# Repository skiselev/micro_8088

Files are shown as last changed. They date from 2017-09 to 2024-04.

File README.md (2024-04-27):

# Micro 8088
IBM XT Compatible Processor Board based on Faraday FE2010/FE2010A chipset

## Introduction
Micro 8088 is an easy to build IBM PC/XT compatible processor board. It uses a fairly common Faraday FE2010/FE2010A chipset, that implements most of IBM PC/XT LSIs (Intel 8xxx ICs) and glue logic. Micro 8088 uses SRAM ICs to implement the system RAM, and a Flash ROM IC to store the BIOS, further reducing the number of components, and simplifying the build process.

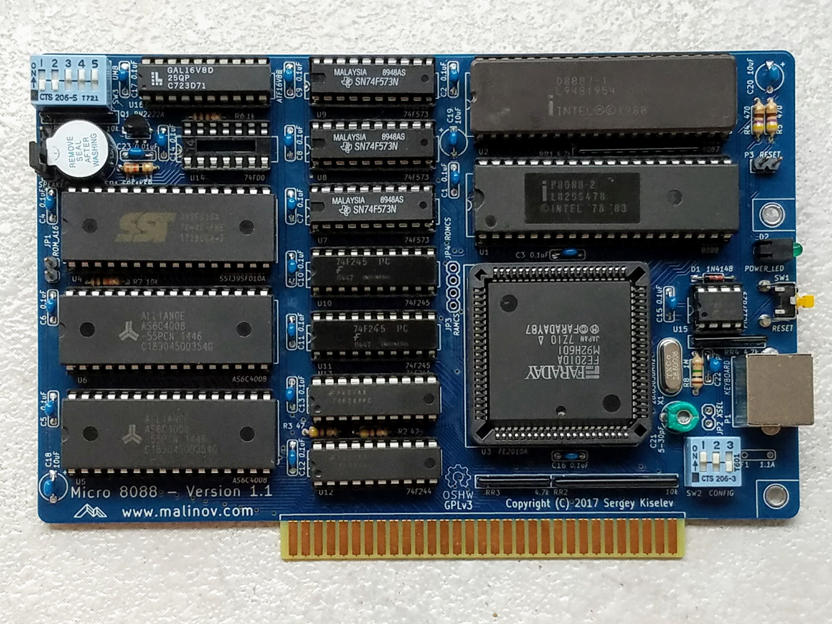
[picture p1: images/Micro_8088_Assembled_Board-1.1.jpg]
Micro 8088 V1.1 Assembled Board


## Specifications
* Processor: Intel 8088 or compatible, NEC V20
  * Supports IBM PC/XT standard 4.77 MHz CPU frequency and, when using FE2010A chipset, 7.16 MHz and 9.54 MHz CPU frequencies
* Coprocessor: Intel 8087
* [Faraday FE2010/FE2010A](Documentation/Faraday-XT_Controller-FE2010A.md) chipset, implementing the following components:
  * One 8237 direct memory access controller (DMAC)
  * One 8259 programmable interrupt controller (PIC)
  * One 8254 programmable interval timer (PIT)
  * One 8255 programmable peripheral interface (PPI)
  * Clock generation, and glue logic
* RAM: 512 KiB or 640 KiB base memory; Up to 192 KiB UMBs. Implemented using SRAM
* ROM: 64 KiB. Implemented using 128 KiB Flash ROM
* 8-bit ISA interface
* PS/2 compatible keyboard connector; built in AT2XT converter

## Hardware Documentation

### Schematic and PCB Layout

[Schematic - Version 1.1](KiCad/8088-FE2010A-SBC-Schematic-1.1.pdf)

[PCB Layout - Version 1.1](KiCad/8088-FE2010A-SBC-Board-1.1.pdf)

[PCB Layout - Version 1.2](KiCad/8088-FE2010A-SBC-Board-1.2.pdf)

[PCB Layout - Version 1.3](KiCad/8088-FE2010A-SBC-Board-1.3.pdf)

### Building Insturctions

Please refer to [Building Instructions](Building_Instructions.md) page for detailed instructions.

### Faraday FE2010/FE2010A Information

Please refer to [Faraday FE2010A documentation](Documentation/Faraday-XT_Controller-FE2010A.md) and [Faraday FE2010 datasheet](Documentation/Faraday-XT_Controller-FE2010.pdf) for detailed information about Faraday FE2010/FE2010A chipsets.

*Note: CPU clock frequency switching (turbo mode) is only implemented in Faraday FE2010A chipset (not in FE2010).*

### Jumpers, Connectors, and Switches

#### P1 - PS/2 Keyboard
Pin | Description
--- | -----------
1   | Keyboard data
2   |	Unused
3   |	GND
4   |	+5V
5   |	Keyboard clock
6   |	Unused

#### P2 - Speaker
Pin | Description
--- | -----------
1   | Speaker output
2   | Internal Speaker input*
3   | Unused
4   |	+5V

*Note: To enable internal speaker connect a jumper across pins 1-2*

#### P3 - Reset Switch
Pin | Description
--- | -----------
1   | Reset input
2   | Ground

#### JP1 - Select Flash ROM area mapped to 0xF0000-0xFFFFF
Position | Description
-------- | -----------
*open (default)* | Map lower 64 KiB of the Flash ROM to 0xF0000-0xFFFFF
closed   | Map upper 64 KiB of the Flash ROM to 0xF0000-0xFFFFF

#### JP2 - Select X1 Crystal Frequency
Position | Description
-------- | -----------
open     | Use 14.31818 MHz crystal
*closed (default)* | Use 28.63636 MHz crystal

*Note: 14.31818 MHz crystal supports 4.77 MHz and 7.16 MHz CPU clock frequencies; 28.63636 MHz crystal additionally supports 9.55 MHz CPU clock frequency*

#### JP3 - RAM Chip Select Source
Position | Description
-------- | -----------
*open (default)* | Use SPLD (U16)
closed   | Use FE2010A (U3)

*Note: FE2010A only generates RAM chip select for the base RAM (lower 640 KiB). It does not generate RAM chip select for UMBs, and therefore SPLD (U16) is required to implement UMBs*

#### JP4 - Flash ROM Chip Select Source
Position | Description
-------- | -----------
*open (default)* | Use SPLD (U16)
closed   | Use FE2010A (U3)

*Note: FE2010A does not generate chip select for memory write cycles, therefore it does not support in-system BIOS upgrades*

#### SW1 - Reset Switch
Press SW1 to reset the system

#### SW2 - System Configuration
Position	| Description
-------- | -----------
SW2.1 = OFF, SW2.2 = OFF | MDA or Hercules
SW2.1 = ON, SW2.2 = OFF  | CGA, 80x25
SW2.1 = OFF, SW2.2 = ON  | CGA, 40x25
SW2.1 = ON, SW2.2 = ON   | None, EGA, or VGA
SW2.3 = OFF | Disable keyboard 0xE0 scan code pass through
SW2.3 = ON | Enable keyboard 0xE0 scan code pass through

#### SW3 - UMB Configuration
Position	| Description
-------- | -----------
SW3.1 = ON | Map 0xC0000-0xC7FFF to RAM 
SW3.2 = ON | Map 0xC8000-0xCFFFF to RAM 
SW3.3 = ON | Map 0xD0000-0xD7FFF to RAM 
SW3.4 = ON | Map 0xD8000-0xDFFFF to RAM 
SW3.5 = ON | Map 0xE0000-0xEFFFF to RAM

*Note: SPLD (U16) is required to implement UMBs. This switch is not used in systems without SPLD*

### Bill of Materials - Versions 1.1, 1.2, and 1.3

[Micro 8088 project on Mouser.com](https://www.mouser.com/ProjectManager/ProjectDetail.aspx?AccessID=57e2f0df1d) - View and order all components except of the Faraday FE2010A chipset, and the PCB.
[Micro 8088 project on OSH Park](https://oshpark.com/shared_projects/xbWzfre6) - View and order the PCB.

Component type    	| Reference | Description                       | Quantity | Possible sources and notes 
------------------ | --------- | --------------------------------- | -------- | --------------------------
PCB                |           | Micro 8080 PCB - Version 1.1, 1.2, or 1.3 | 1        | Refer to the [RetroBrew Computers Board Inventory](https://retrobrewcomputers.org/doku.php?id=boardinventory#xi_8088_project_sergey_kiselev) page for ordering information, or order from a PCB manufacturer of your choice using provided Gerber or KiCad files
Integrated Circuit | U1        | Intel 8088, 80C88, or NEC V20 CPU | 1        | eBay, Mouser (expensive) - [968-CP80C88-2Z](https://www.mouser.com/ProductDetail/968-CP80C88-2Z)
Integrated Circuit | U2        | Intel 8087 FPU                    | 1        | Optional, eBay
Integrated Circuit | U3        | Faraday FE2010A                   | 1        | eBay, can be replaced with [Proton PT8010AF](https://github.com/skiselev/micro_8088/blob/master/Documentation/Proton-XT_Controller-PT8010AF.md)
Integrated Circuit | U4        | SST39SF010A Flash ROM, DIP-32 package | 1    | Mouser [804-39SF010A7CPHE](https://www.mouser.com/ProductDetail/804-39SF010A7CPHE)
Integrated Circuit | U5, U6    | AS6C4008 SRAM, DIP-32 package     | 2        | Mouser [913-AS6C4008-55PCN](https://www.mouser.com/ProductDetail/913-AS6C4008-55PCN)
Integrated Circuit | U7 - U9   | 74F573 Octal D-Type Latch         | 3        | Mouser [595-SN74F573N](https://www.mouser.com/ProductDetail/595-SN74F573N)
Integrated Circuit | U10, U11  | 74F245 Octal Bus Transceiver      | 2        | Mouser [595-SN74F245N](https://www.mouser.com/ProductDetail/595-SN74F245N)
Integrated Circuit | U12, U13  | 74F244 Octal Buffer               | 2        | Mouser [595-SN74F244N](https://www.mouser.com/ProductDetail/595-SN74F244N)
Integrated Circuit | U14       | 74F00 Quad 2-Input NAND Gate      | 1        | Mouser [595-SN74F00](https://www.mouser.com/ProductDetail/595-SN74F00N). **Important note: install either U14 or U16, not both together**
Integrated Circuit | U15       | PIC12F629 Microcontroller         | 1        | Mouser [PIC12F629-I-P](https://www.mouser.com/ProductDetail/579-PIC12F629IP)
Integrated Circuit | U16       | ATF16V8B SPLD                     | 1        | Mouser [556-AF16V8B15PU](https://www.mouser.com/ProductDetail/556-AF16V8B15PU). **Important note: install either U14 or U16, not both together**
IC Socket          | U1, U2    | DIP-40, 600 mil socket            | 2        | Mouser [649-DILB40P223TLF](https://www.mouser.com/ProductDetail/649-DILB40P223TLF)
IC Socket          | U3        | PLCC-84 through hole socket       | 1        | Mouser [517-8484-11B1-RK-TP](https://www.mouser.com/ProductDetail/517-8484-11B1-RK-TP)
IC Socket          | U4-U6     | DIP-32, 600 mil socket            | 3        | Mouser [649-DILB32P223TLF](https://www.mouser.com/ProductDetail/649-DILB32P223TLF)
IC Socket          | U7-U13, U16 | DIP-20, 300 mil socket          | 8        | Mouser [649-DILB20P-223TLF](https://www.mouser.com/ProductDetail/649-DILB20P-223TLF)
IC Socket          | U14       | DIP-14, 300 mil socket            | 1        | Mouser [649-DILB14P-223TLF](https://www.mouser.com/ProductDetail/649-DILB14P-223TLF)
IC Socket          | U15       | DIP-8, 300 mil socket             | 1        | Mouser [649-DILB8P223TLF](https://www.mouser.com/ProductDetail/649-DILB8P223TLF)
Diode              | D1        | 1N4148                            | 1        | Mouser [512-1N4148](https://www.mouser.com/ProductDetail/512-1N4148)
LED                | D2        | 3 mm, green LED indicator         | 1        | Mouser [LTL-4231NHBP](https://www.mouser.com/ProductDetail/859-LTL-4231NHBP)
Transistor         | Q1        | PN2222A, 2.54mm lead spacing      | 1        | Mouser [512-PN2222ATA](https://www.mouser.com/ProductDetail/512-PN2222ATA)
Crystal            | X1        | 28.63636 MHz, 18 pF, HC-49/S      | 1        | Mouser [717-9B-28.63636MAAJB](https://www.mouser.com/ProductDetail/717-9B-28.63636MAAJB)
Speaker            | SP1       | 12 mm speaker                     | 1        | Mouser [665-AT-1224TWTR](https://www.mouser.com/ProductDetail/665-AT-1224TWTR)
Tactile Button     | SW1       | 6 mm tactile button, right angle  | 1        | Mouser [653-B3F-3152](https://www.mouser.com/ProductDetail/653-B3F-3152)
DIP Switch         | SW2       | 3 positions                       | 1        | Mouser [774-2063](https://www.mouser.com/ProductDetail/774-2063)
DIP Switch         | SW3       | 5 positions                       | 1        | Mouser [774-2065](https://www.mouser.com/ProductDetail/774-2065)
Connector          | P1        | 6 pin Mini DIN, purple            | 1        | Mouser [806-KMDGX-6S-BS](https://www.mouser.com/ProductDetail/806-KMDGX-6S-BS)
Pin Header         | P2, JP3-JP4 | 4 pin header, 2.54 mm pitch     | 2        | Mouser [649-68002-104HLF](https://www.mouser.com/ProductDetail/649-68002-104HLF)
Pin Header         | P3, JP1-JP2 | 2 pin header, 2.54 mm pitch     | 3        | Mouser [649-68002-102HLF](https://www.mouser.com/ProductDetail/649-68002-102HLF)
Capacitor          | C1 - C17  | 0.1 uF, MLCC, 5 mm lead spacing   | 17       | Mouser [810-FG28X7R1H104KNT6](https://www.mouser.com/ProductDetail/810-FG28X7R1H104KNT6)
Capacitor          | C18 - C20 | 10 uF, MLCC, 5 mm lead spacing    | 3        | Mouser [810-FG28X5R1E106MR06](https://www.mouser.com/ProductDetail/810-FG28X5R1E106MR06)
Trimmer Capacitor  | C21       | 6.5-30 pF, 5 mm lead spacing      | 1        | Mouser [659-GKG30015](https://www.mouser.com/ProductDetail/659-GKG30015). Note: Trimmer capacitor is used to fine-tune 14.31818 MHz OSC frequency, and it might be needed when using CGA graphics with composite display. If not using CGA with composite display, a 22pF or so ceramic capacitor can be used instead, such as Mouser [810-FG28C0G1H220JNT6](https://www.mouser.com/ProductDetail/810-FG28C0G1H220JNT6)
Capacitor          | C22       | 47 pF, MLCC, 5 mm lead spacing    | 1        | Mouser [810-FG28C0G1H470JNT6](https://www.mouser.com/ProductDetail/810-FG28C0G1H470JNT6)
Capacitor          | C23       | 0.01 uF, MLCC, 5 mm lead spacing  | 1        | Mouser [810-FG28X7R1H103KNT6](https://www.mouser.com/ProductDetail/810-FG28X7R1H103KNT6)
Resistor Array     | RR1       | 4.7 k, bussed, 10 pin SIP         | 1        | Mouser [652-4610X-1LF-4.7K](https://www.mouser.com/ProductDetail/652-4610X-1LF-4.7K)
Resistor Array     | RR2       | 10 k, bussed, 10 pin SIP          | 1        | Mouser [652-4610X-1LF-10K](https://www.mouser.com/ProductDetail/652-4610X-1LF-10K)
Resistor Array     | RR3, RR4  | 4.7 k, bussed, 6 pin SIP          | 2        | Mouser [652-4606X-1LF-4.7K](https://www.mouser.com/ProductDetail/652-4606X-1LF-4.7K)
Resistor Array     | RR5       | 10 k, bussed, 6 pin SIP           | 1        | Mouser [652-4606X-1LF-10K](https://www.mouser.com/ProductDetail/652-4606X-1LF-10K)
Resistor           | R1        | 33 ohm, through hole              | 1        | Mouser [603-MFR-25FBF52-33R](https://www.mouser.com/ProductDetail/603-MFR-25FBF52-33R)
Resistor           | R2, R3    | 47 ohm, through hole              | 2        | Mouser [603-MFR-25FBF52-47R](https://www.mouser.com/ProductDetail/603-MFR-25FBF52-47R)
Resistor           | R4, R5    | 470 ohm, through hole             | 2        | Mouser [603-MFR-25FBF52-470R](https://www.mouser.com/ProductDetail/603-MFR-25FBF52-470R)
Resistor           | R6        | 1 kohm, through hole              | 1        | Mouser [603-MFR-25FBF52-1K](https://www.mouser.com/ProductDetail/603-MFR-25FBF52-1K)
Resistor           | R7        | 10 kohm, through hole             | 1        | Mouser [603-MFR-25FBF52-10K](https://www.mouser.com/ProductDetail/603-MFR-25FBF52-10K)
Resistor           | R8        | 1 Mohm, through hole              | 1        | Mouser [603-MFR-25FBF52-1M](https://www.mouser.com/ProductDetail/603-MFR-25FBF52-1M)
Fuse               | F1        | 1.1A polyfuse, 5.08 mm lead pitch | 1        | Mouser [650-RUSBF110-2](https://www.mouser.com/ProductDetail/650-RUSBF110-2)
ISA Bracket        |           | Keystone Electronics 9202         | 1        | Mouser [534-9202](https://www.mouser.com/ProductDetail/534-9202)
Screw              |           | 4-40 x 1/4" Screw                 | 2        | Mouser [534-9900](https://www.mouser.com/ProductDetail/534-9900)

## Firmware Documentation

### System BIOS

Micro 8088 uses a modified version of [Xi 8088](http://www.malinov.com/Home/sergeys-projects/xi-8088) BIOS. The BIOS binary images are provided in [BIOS](BIOS) directory. The BIOS source code is available in [8088_bios GitHub repository](https://github.com/skiselev/8088_bios)

#### Turbo Mode Switching

The BIOS keyboard handler uses the following key combinations to switch the CPU clock frequency:
* **Ctrl-Alt-Keypad -** - Normal 4.77 MHz CPU clock frequency
* **Ctrl-Alt-Keypad \*** - Turbo 7.16 MHz CPU clock frequency
* **Ctrl-Alt-Keypad +** - Turbo 9.55 MHz CPU clock frequency (works only on systems with 28.63636 MHz X1 crystal)

Note that the BIOS does not, and possibly can not check if the installed CPU and the FPU are actually capable of running at higher clock frequencies. Turning on the turbo mode in a system with 5 MHz CPU can make it unstable.

### AT2XT Firmware

Micro 8088 integrates an AT2XT keyboard converter, implemented using PIC12F629 (U15). The firmware for this microcontroller is availabe from the [minuszerodegrees.net](http://minuszerodegrees.net/at2xtkb/XTATKEY_094.zip) and the [Vintage Computer Federation AT2XT page](https://forum.vcfed.org/index.php?threads/at2xt-keyboard-converter.26861/page-4#post-1242916). The HEX file with the firmware can be extracted from XTATKEY_094.zip.

### SPLD Fuse Maps

An optional ATF16V8/GAL16V8 SPLD (U16) allows using spare SRAM space for UMBs, and implements Flash ROM write access. The fuse maps for the SPLD are provided in [SPLD](SPLD) directory of this repository. The [SPLD/micro_8088_prod.jed](SPLD/micro_8088_prod.jed) fuse map should be used for production applications.

## Changes
* Version 1.3
  * Update silkscreen:
    * SW2.3 - fix the description for the *ON* position
    * Add a warning about installing either U14 or U16, but not both
    * Update board version to 1.3
* Version 1.2
  * Update silkscreen:
    * JP2 - change the default to *Closed*
    * Bracket - move rectangles to the back side, add circles around mounting holes on the front side
    * Remove the line around ISA connector
    * Use KiCad OSHW logo
    * Update copyright years to 2017-2018
    * Update board version to 1.2
* Version 1.1
  * Recommend using 74F-series, and update the schematic and the silkscreen accordingly. 74F-series ICs are faster and slightly cheaper than 74ALS-series
  * Add 74F573 latch for latching A8-A11 signals. This fixes the DMA issue
  * Use 74F244 to buffer OSC and CLK signals
  * Use AS6C4008 for the second SRAM (U6) instead of AS6C1004. This resolves the AS6C1004 TTL compatibility issue
  * Use 74F00 for generating chip select signal for the second SRAM (U6), and for inverting the speaker signal
  * Add an optional SPLD (U16) to implement UMBs
  * Use 128 KiB Flash ROM instead of 32 KiB EEPROM. It is cheaper, and has twice more storage space
  * Use buffered /MEMR and /MEMW signals for SRAM and BIOS ROM
  * PCB dimensions changed from 5" x 4.3" to 6" x 4"
* Version 1.0
  * Initial version

## Known Issues
* Version 1.2
  * SW2.3 description on the back silkscreen incorrectly references SW1.3 for the *ON* position
* Version 1.1
  * JP2 description on the back silkscreen suggests that the default JP2 position is *Open*. Since the recommended chipset is FE2010A and the recommended crystal frequency is 28.63636 MHz, the default JP2 position should be *Closed*
  * Update the silkscreen near ISA bracket mounting holes: The rectangles should be moved to the back silkscreen, and screw head sized circles should be shown on the front skilscreen
* Version 1.0
  * AS6C1008 (U6) does not have TTL compatible inputs causing instability with 640 KiB memory configruation
    * Workaround: use CMOS transceiver U11, e.g. 74AHCT245
  * DMA doesn't work properly.
    * This is due to A8-A11 address lines not being latched.
    * Workaround: add a 74F573 latch, and connect AA8-AA11 and A8-AA11 through it

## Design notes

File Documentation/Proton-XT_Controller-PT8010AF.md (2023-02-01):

# Proton PT8010AF - PC Bus, CPU, and Peripheral Controller

## Introduction

Proton PT8010AF controller was used in several late 80's XT-compatible motherboards. It appears to be a clone of [Faraday FE2010A](Faraday-XT_Controller-FE2010A.md).

Unfortunately I was not able to find Proton PT8010AF datasheet, so I [reverse-engineered a PT8010AF-based motherboard](https://github.com/skiselev/Proton_Turbo_XT).
This work showed that Proton PT8010AF has exactly the same pinout as Faraday FE2010A. I also acquired a PT8010AF, installed in a Micro 8088 system, and tested it.

## Can Faraday FE2010A be replaced with Proton PT8010AF?

Proton PT8010AF will work instead of Faraday FE2010A in a Micro 8088 system. I haven't tested other systems, but it is very likely that it will work there too.

## Differences between Proton PT8010AF and Faraday FE2010A

During my testing so far, I found two differences between Proton PT8010AF and Faraday FE2010A documented below.

### DRAM Refresh

Both chipsets implement IBM PC/XT compatible memory refresh using 8253 PIT Channel 1. DRAM refresh inserts DMA cycles, so it slows down the system. My measurements show up to 15% slowdown. In both chipsets it is possible to disable the DRAM refresh if it is not needed, for example in systems like Micro 8088, that use SRAM. 

It appears that in both chipsets, the refresh is disabled by writing **0x54** to port **0x43** (PIT control register). And it enabled by a consecutive write to port **0x41** (PIT Channel 1), typically, the value written is **0x12**, which results in a 15 usec refresh interval - same as on IBM PC/XT.

There are a few differences in behavior of the PIT registers between Faraday FE2010A and Proton PT8010AF:

* When refresh is enabled, on PT8010AF, reads from **0x41** (PIT Channel 1, should result in current counter content) return numbers from **0x00** to **0x0F** (perhaps higher numbers too, theoretically should be in **0x00** to **0x11** interval), while on FE2010A such reads seem to result in either **0x10** or **0x05**.
* When refresh is enabled, on FE2010A, writing **0x40** to port **0x54** results in disabling refresh. Consecutive reads from **0x41** will result in **0x12** value, while on PT8010AF, writing **0x40** to port **0x54** does not disable refresh

### IORDY Timing

It appears that Proton PT8010AF samples IORDY input later than Faraday FE2010A does. The difference in behavior in my case is observable when running a Micro 8088 system
with a Trident TVGA9000i card, in the 9.54 MHz Turbo mode, with zero memory wait states (port 0x63 - Chipset Configuration Register, bits 7 and 5 set to 1).
In this case with a FE2010A, I observe glitches on video output, apparently resulting from the chipset ignoring VGA controller IO_CH_RDY requests to insert wait cycles
(video controllers almost always insert wait cycles when accessing video memory), while with Proton PT8010AF there are no glitches and wait states are inserted correctly.
I suspect that there is a difference in the time when IORDY is sampled, and perhaps Proton PT8010AF samples it a bit later, giving VGA controller an opportunity to activate it
before it gets sampled.

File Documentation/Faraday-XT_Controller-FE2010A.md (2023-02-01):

# Faraday FE2010A - PC Bus, CPU, and Peripheral Controller

## Introduction

Faraday FE2010A was manufactured in late 1980's and perhaps early 1990's by Western Digital Corp., which had acquired Faraday Electronics Inc. in 1987.
Faraday FE2010A is an enhanced version of Faraday FE2010 controller, the main difference is support for higher CPU clock frequencies (aka turbo mode).
Faraday FE2010A was one of the earlier PC chipsets. It implements the Intel 8xxx ICs (excluding the microprocessor and the math coprocessor)
and the glue logic found on an IBM XT motherboard. Thus, it allows implementing an XT compatible system with a minimal number of components.

I was not able to find the original Faraday FE2010A datasheet, and this document is an attempt to combine the information gathered from
various sources and experimentation.

## Detailed Description

Most of the hardware specifications of Faraday FE2010A, including the pinout are similar to Faraday FE2010, and they are documented in
the [Faraday FE2010 datasheet](https://github.com/skiselev/micro_8088/blob/master/Documentation/Faraday-XT_Controller-FE2010.pdf).

### Hardware Differences Between Faraday FE2010A and Faraday FE2010

Faraday FE2010 only supports PC/XT standard 4.77 MHz CPU clock frequency using 14.31818 crystal oscillator.
Faraday FE2010A can provide 4.77 MHz and 7.15 MHz CPU clock frequencies using 14.31818 MHz crystal oscillator,
or 4.77 MHz, 7.15 MHz, and 9.54 MHz CPU clock frequencies using 28.63636 MHz crystal oscillator.
Faraday FE2010A uses XSEL signal - pin 16 (previously unused on FE2010) to indicate the crystal frequency as follows:

* 14.31818 MHz crystal oscillator - pin 16 pulled up, e.g. connected to +5V using a 4.7 kohm resistor
* 28.63636 MHz crystal oscillator - pin 16 pulled down, e.g. connected to the ground

It seems to be a difference in the way Faraday FE2010A implements DRAM controller: Faraday FE2010 has only a single bit in the
Configuration Register to set the DRAM size, while Faraday FE2010A implements two such bits.

## Faraday FE2010A Programming

### I/O Map

Address     | I/O Resource
------------|-------------
0x00 - 0x0F | 8237 Compatible DMA Controller
0x10 - 0x1F | Reserved
0x20 - 0x21 | 8259 Compatible Interrupt Controller
0x22 - 0x3F | Reserved
0x40 - 0x42 | 8253 Compatible Timer
0x44 - 0x5F | Reserved
0x60        | Keyboard Data Register
0x61        | Control Register (aka Port B)
0x62        | Switch Register (aka Port C)
0x63        | Configuration Register
0x64 - 0x6F | Reserved
0x70 - 0x7F | Unused
0x81 - 0x83 | DMA Page Registers
0x84 - 0x9F | Reserved
0xA0        | NMI Mask Register
0xA1 - 0xFF | Reserved

The I/O space is decoded to be compatible with the IBM PC I/O decoding scheme. This means that the upper 6 address lines are not
used in decoding the I/O address. To further clarify this, the address of the NMI Mask Register is located at XXXX XX00 1010 000 binary.
X indicates a "don't care" condition.

### Keyboard Data Register

The Keyboard Data Register is a read only register that is used to read data from the keyboard. When a character is in the Keyboard Data
Register, interrupt 1 will be sent to the Interrupt Controller. The Keyboard Data Register may be cleared by setting bit 7 of Control
Register (setting it to 1 and resetting it to 0).

### DMA Page Registers

The Page Registers are write only registers used to generate address bits 16 - 19 during a DMA transfer.

Address | Page Register
--------|--------------
81      | DMA Channel 2
82      | DMA Channel 3
83      | DMA Channel 1

Data Bit | Function
---------|---------
0        | Address Bit 16
1        | Address Bit 17
2        | Address Bit 18
3        | Address Bit 19

### NMI Mask Register

The NMI Mask Register (I/O Address 0xA0) is used to enable the NMI to the CPU. It is a write only register

Data Bit | Function
---------|---------
0 - 6    | Not Used
7        | 1 = Enable NMI

### Control Register

The Control Register (I/O Address 0x61) emulates the behavior of 8255 PPI Port B, as implemented in the standard IBM XT design.
It is a read/write register: writing it controls the corresponding functions, reading it returns the last written value.

Data Bit | Function
---------|---------
0        | Timer 2 Gate
1        | Enable Speaker
2*       | Switch Select
3*       | Not Used
4        | Disable Parity Check
5        | Disable I/O Check
6        | Enable Keyboard Clock
7        | Clear Keyboard Data Register

*Note: Bits 2 and 3 are swapped when compared to the standard IBM PC architecture*

### Switch Register

The Switch Register (I/O Address 0x62) is a read/write register.
In read mode it emulates the behavior of 8255 PPI Port C, as implemented in the standard IBM XT design.
In write mode it allows setting the values for the emulated IBM XT configuration DIP switch (that can be later read from this register).

#### Switch Register Functions - Write Mode

Data Bit | Function
---------|-----------------
0        | Not Used (SW1 value)
1        | 8087 Installed (SW2 value)
2 - 3    | On Board System Memory Size (SW3 - SW4 values)
4 - 5    | Not Used (SW5 - SW6 values are set using the actual inputs from VID0 and VID1 pins)
6 - 7    | Number of Floppies (SW7 - SW8 values)

#### Switch Register Functions - Read Mode

The switch values (bits 0 - 3) depend on the Switch Select bit (bit 2) setting in the control register.

Data Bit | Function with Switch Select = 0
---------|-----------------
0 - 1    | VID0 and VID1 pins (SW5 and SW6 values)
2 - 3    | Number of Floppies, as written to bits 6 - 7 of this register (SW7 - SW8 values)
4        | Timer 2 Output
5        | Timer 2 Output
6        | I/O Channel Check
7        | RAM Parity Check

Data Bit | Function with Switch Select = 1
---------|-----------------
0        | Value written to bit 0 of this register (SW1 value)
1        | 8087 Installed, as written to bit 1 of this register (SW2 value)
2 - 3    | On Board System Memory Size as written to bits 2 - 3 of this register (SW3 - SW4 values)
4        | Timer 2 Output
5        | Timer 2 Output
6        | I/O Channel Check
7        | RAM Parity Check

### Configuration Register

The Configuration Register (I/O Address 0x63) is a write only register that is used for FE2010A configuration.
If bit 3 is written, bits 0 - 4 of this register and the switch register are locked in that they may not be written to.
This lock is removed by a system reset.

Data Bit | Function
---------|----------
0        | Disable Parity Checker
1        | Enable 8087 NMI
2        | On Board RAM size (bit 0)
3        | lock register (bits 0-4)
4        | On Board RAM size (bit 1)
5        | Fast Mode (0 RAM wait states)
6        | 7.15 MHz CPU clock
7        | 9.54 MHz CPU clock

Data bit 0 must always be one on systems without parity checking, for example in systems using SRAM.
Data bit 1 most always be zero when no 8087 is present and data bit 1 must always be a one when 8087 is present.

#### On Board RAM Size

On Board RAM size refers to the number of banks of memory supported by the FE2010A DRAM controller

Configuration Register Bit 4 | Configuration Register Bit 2 | Memory Banks | On Board RAM size
-----------------------------|------------------------------|--------------|------------------
0                            | 1                            | 1            | 256K
1                            | 0                            | 2            | 512K
0                            | 0                            | 3            | 640K

*Note: On Board RAM size settings doesn't seem to affect systems using SRAM (need check if they are not used to determine on board memory size for wait state generation)*

#### CPU Clock Frequency and Wait States

Configuration Register Bit 7 | Configuration Register Bit 6 | Configuration Register Bit 5 | CPU Speed | I/O Wait States | On Board Memory Wait States | Memory Bus Wait States
-----------------------------|------------------------------|------------------------------|-----------|-----------------|-----------------------------|----------------------- 
0                            | 0                            | X                            | 4.77 MHz  | 1               | 0                           | 0
0                            | 1                            | 0                            | 7.15 MHz  | 4               | 0                           | 2
0                            | 1                            | 1                            | 7.15 MHz  | 4               | 0                           | 0
1                            | 0                            | 0                            | 9.54 MHz  | 6               | 0                           | 4
1                            | 1                            | 0                            | 9.54 MHz  | 4               | 0                           | 2
1                            | 0                            | 1                            | 9.54 MHz  | 6               | 0                           | 0
1                            | 1                            | 1                            | 9.54 MHz  | 4               | 0                           | 0

*Note: It appears that when running at 9.54 MHz, the CPU clock duty cycle is 50% (instead of 33%). This potentially can cause issues with some 8088 CPUs.*

### Counter/Timer Control

The timer section of the FE2010A is similar in design to the Intel 8253 Programmable Interval Timer.
The timer inputs are internally connected to a 1.19 MHz clock and the outputs are appropriately connected to configure the timer
for the PC/XT architecture. Channel 0 is used by the system to provide a real time clock to interrupt 0. Channel 1 is directly connected
to the DMA channel 0 request line and provides timing for the Dynamic RAM refresh. An I/O read from port 0x41 turns refresh on and
an I/O write to port 0x43 selecting counter 1 turns refresh off. The channel 2 output is connected to the SPKR signal and provides tone
generation.

The timer may be programmed in the same manner as the 8253. It should be noted, however, that the modes of the timer defined above are
hardwired in the component and can not be changed. The timer has four registers located at I/O addresses 0x40 to 0x43.

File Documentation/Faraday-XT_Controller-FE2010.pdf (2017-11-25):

Powered by ICminer.com Electronic-Library Service CopyRight 2003

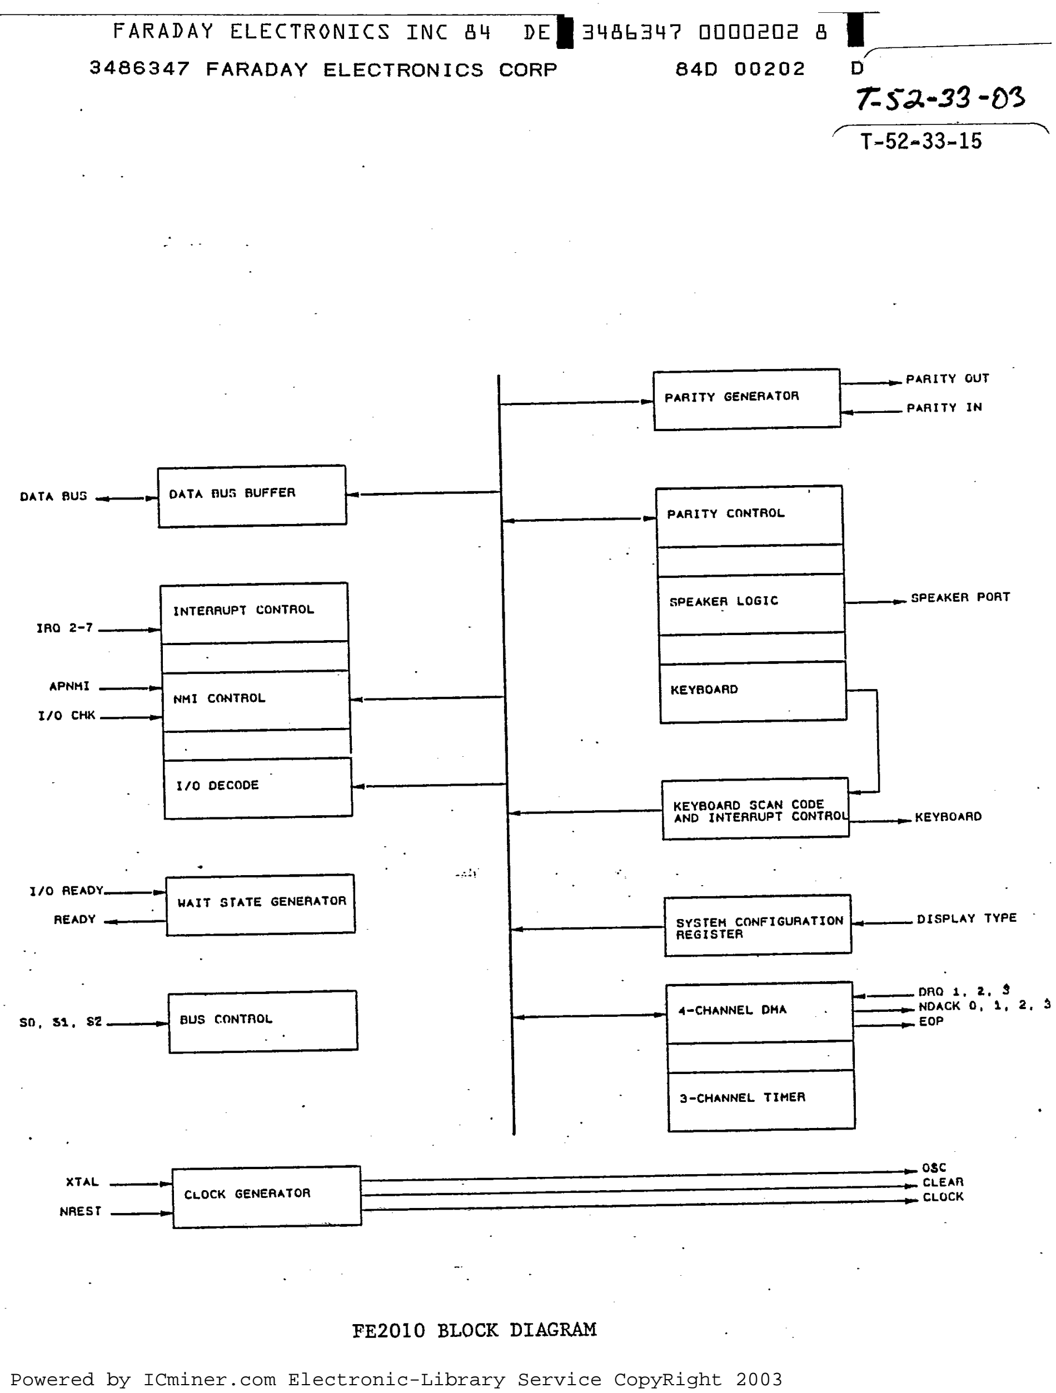
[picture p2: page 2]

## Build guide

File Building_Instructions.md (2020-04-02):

# Micro 8088 - Building Instructions

## Prerequisites

### Tools, Equipment, and Supplies

* Soldering iron with a fine tip. Temperature controlled soldering station is recommended
* Needle nose pliers for forming components' leads
* Small side cutters for cutting components' leads
* Universal programmer capable of programming SST39F010A Flash ROM ICs, PIC12F629 Microcontrollers, and ATF16V8B SPLDs. For example, MiniPro TL866CS or MiniPro TL866A
* Multimeter with frequency measurement, an oscilloscope, or a logic analyzer can be beneficial for troubleshooting
* Desk lamp, magnifying glass
* Electric drill and drill bits for drilling holes in the ISA bracket
* Small semi-round file for smoothing holes in the ISA bracket
* PLCC IC extraction tool
* Small flat and Philips screwdrivers
* Solder suitable for soldering electronics. For example: rosin core Sn63/Pb37, Sn60/Pb40, or a lead-free solder such as Sn96.5/Ag3.0/Cu0.5 (sometimes referred to as SAC305)
* Solder wick for removing excess of solder
* 99% Isopropyl Alcohol for removing the excess of flux after soldering
* Lint free wipes, used toothbrush, cotton swabs for cleaning the PCB before and after soldering

### Parts

#### Procuring Parts
The list of parts provided in the [Bill of Materials](README.md#bill-of-materials---version-11) section of the [README.md](README.md) file. It also provides the recommended sources for the parts.
Most of the parts are available from electronic components distributors such as [Mouser](https://www.mouser.com/ProjectManager/ProjectDetail.aspx?AccessID=57e2f0df1d) and [Digi-Key](https://www.digikey.com).
Many components are also available, frequently cheaper, from smaller stores, such as [Unicorn Electronics](http://www.unicornelectronics.com/), or on eBay.

The Micro 8088 PCBs are provided by the members of [RetroBrew Computers group](https://retrobrewcomputers.org/doku.php?id=boardinventory#xi_8088_project_sergey_kiselev).
Alternatively they can be ordered from a PCB manufacturing service, such as [OSH Park](https://oshpark.com/shared_projects/xbWzfre6),
using [Gerber](gerber) or [KiCad](KiCad) files provided in this GitHub repository.

Faraday FE2010A chip is available from a few sellers on eBay, and can be also obtained from some Chinese IC distributors.

The 8088 processor is no longer manufactured, but still can be obtained from several sources.
It can be replaced with CMOS version - 80C88, which is still manufactured by [Renesas/Intersil](https://www.renesas.com/us/en/products/space-harsh-environment/harsh-environment/microprocessors-peripherals/device/80C88.html).
Alternatively NEC V20 CPU can be used, this CPU is slightly faster than the original 8088, and supports 80186+ instruction set.

The 8087 math coprocessor is an optional component. Not many programs use it, and not many PCs/XTs and compatible computers in 1980's had it installed.
Still, if needed it can be obtained on eBay. Intel D8087-1 is the recommended part (-1 suffix means 10 MHz clock frequency).

#### Parts Replacement

* The recommended logic family is the Fast TTL 74F-series
  * Possible replacements are Advanced Low-Power Schottky 74ALS-series, or CMOS 74ACT-series logic
  * 74LS, 74HCT, 74AHCT series logic might work as well, but have not been tested
* The recommended CPU is 10 MHz 8088, for example AMD P8088-1, or Siemens SAB 8088-1-P
  * Possible replacements are 10 MHz or higher NEC V20 (μPD70108C-10) or NEC V20HL (μPD70108HCZ-10, μPD70108HCZ-16)
  * 8 MHz 8088-2, 80C88-2, and NEC V20 (μPD70108C-8) parts might work as well
* The recommended SPLD is Atmel ATF16V8B. It can be replaced with Lattice GAL16V8D or similar
  * Make sure that your programmer supports the SPLD type you're planning to use
  * Note that SPLD part is optional, and a 74F00 logic IC can be used instead. See the [Optional Components](#optional-components) section below.
* The recommended Flash ROM part is Microchip SST39SF010A
  * Other 128 KiB, 5V-only Flash ROM ICs can be used, for example Atmel AT29C010, Winbond W29EE011, Greenliant GLS29EE010, AMD Am29F010B
* The recommended SRAM part is Alliance Memory AS6C4008-55PCN
  * Other 512 KiB, TTL compatible SRAM ICs should work, for example Hitachi HM628512, BSI BS62LV4006PC
* It is recommended to use ceramic multilayer capacitors with 5 mm lead pitch
  * It is possible to use 2.5 mm lead pitch or axial capacitors by forming their leads accordingly
  * Electrolytic or tantalum capacitors can be used for C18-C20 10 uF. Make sure to observe the polarity in this case
* Either 28.63636 MHz or 14.81313 MHz crystal X1 can be used. The 28.63636 MHz is the recommended value. Make sure to set JP2 according to the selected crystal frequency

#### Optional Components

* Either the SPLD IC U16 or the 74F00 logic IC U14 should be installed (but not both together)
  * The SPLD provides UMB (upper memory blocks) support, and supports read/write access to the Flash ROM
  * The 74F00 supports only 640 KiB of base RAM, and allows read-only access to the Flash ROM. It is not needed to install the DIP switch SW3 if using 74F00
 * 8087 math co-processor U1 is completely optional
* The second SRAM U6 is optional, the system memory size will be limited to 512 KiB if that IC is not installed
* DIP IC sockets are optional, but it is highly recommended to install them for the following ICs:
  * Processor and math coprocessor - U1 and U2
  * PIC12F629 microcontroller - U15
  * SPLD IC - U16
  * Memory ICs - U4 - U6; or at least of the Flash ROM - U4
* The SP1 speaker is optional, and not required if using an external speaker, or no speaker at all

### Other Components Required to Build Functional Computer System

* ISA Backplane
* ISA Graphics/Display Card
* ISA Disk controller and matching disk drives
  * ISA Floppy Disk controller and Floppy drives with cables
  * XT-IDE controller and IDE disk or compact flash card
  * XT-CF-Lite controller and compact flash card
* Optionally - ISA Sound Card
* Power supply (matching the backplane)
* Case or a chassis to mount the system on, or spacers to put under the backplane
* Operating system and software to install on the system
  * MS-DOS
  * File manager and other utilities
  * Diagnostics and benchmark software
  * Games

## Building the Micro 8088 Board

### Build Sequence

1. Inspect the PCB for obvious defects, such as deep scratches or short-circuits between traces
2. Clean the PCB with an alcohol wipe
3. Solder the components, going from lower profile components to higher profile ones
  * Form the leads and solder the D1 diode. Pay attention to the diode's polarity (the black band on the diode should match the band on the silkscreen)
  * Solder the R1-R8 resistors
  * Solder the X1 crystal. You might want to place a piece of a non-conductive plastic, e.g. a nylon washer between the crystal and the PCB
  * Solder the C1-C23 capacitors. Pay attention to the capacitors polarity if using polarized capacitors
  * Solder the RR1-RR5 resistor arrays. Pay attention to the orientation - pin number 1 is usually marked with a dot on the resistor array. Square pads on the PCB are used to mark the first pin
  * Solder all the DIP sockets - U1, U2, U4 - U16. Pay close attention to the orientation of the sockets
  * Solder the PLCC socket for U3. Pay close attention to the orientation of this socket
  * Solder the DIP switches SW2 and SW3
  * Solder the LED D2. Pay attention to the LED polarity. If using a regular 3 mm LED you might want to bend its leads at the right angle, so that it points towards, and sticks through the ISA bracket
  * Solder the Q1 transistor
  * Solder the P2, P3, JP1 - JP4 headers. If using SPLD you don't need solder JP3 - JP4 headers. Also if using 28.62626 MHz crystal, a wire jumper can be installed in place of the JP2 header, or it could be left unpopulated for 14.81313 MHz crystal
  * Solder the SW1 tactile button
  * Solder the F1 polyfuse
  * Solder the P1 Mini DIN connector
  * Solder the SP1 speaker. Pay attention to the polarity
4. Carefully inspect all the solder joints. Re-solder if needed. Optionally use a multimeter to check the board for short-circuits, and for the power supply signals connectivity
5. Clean the board using cotton swaps, wipes, and the toothbrush soaked in alcohol
6. Program the Flash ROM with the [BIOS image](BIOS)
7. Program the PIC12F629 microcontroller with the [AT2XT Firmware](www.vcfed.org/forum/showthread.php?26426-AT2XT-keyboard-converter)
8. If using SPLD, program it with this [fuse map](SPLD/micro_8088_prod.jed)
9. Carefully install ICs into the sockets. Use a hard non-static surface to bend the pins of ICs in DIP packages as needed. Double check the orientation of the ICs. Make sure that all ICs pins are inserted into the sockets, and not bent. Note that FE2010A is installed upside down compared to other ICs.
10. Inspect the completed board once again
11. Install the configuration jumpers, and set the DIP switches as needed. Refer to the [Jumpers, Connectors, and Switches](README.md#jumpers-connectors-and-switches) section of the [README.md](README.md) file
12. Drill the holes in the ISA bracket to match with the PS/2 Mini DIN connector, the reset switch, and the LED. Finish the holes with a file
13. Attach the ISA bracket to the board using two 4-40 x 1/4" screws
14. Install the Micro 8088 board and other ISA cards in the ISA backplane. Connect the power supply
15. Turn on the power, test the board, install your favorite software, and enjoy!

## Troubleshooting Tips

* Inspect your board for any soldering issues
* Check the jumpers and the switches settings. Pay attention to the SW3 switch settings, and make sure that the selected UMB addresses do not conflict with BIOS extension ROMs. For example 0xC0000-0xC7FFF range is normally used by VGA BIOS, make sure that the corresponding switch is turned off when using VGA card
* Make sure that your system is getting the power, and that power supply voltage is within 5%-10% range of the nominal voltage
* Observe the system activity
  * Does it produce any beeping sounds?
  * Using multimeter with frequency measurement or an oscilloscope check for pulses on the key processor and chipset signals:
    * OSC, and CLK (CPU clock) signals
    * AD0 signal on the CPU, A0 signal on ISA bus
    * /MEMR, /MEMW, /IOR, /IOW signals on ISA bus
  * Using an ISA POST card or a backplane with a POST display, check if system outputs any POST codes. If so, is there any particular code it is getting stuck on?

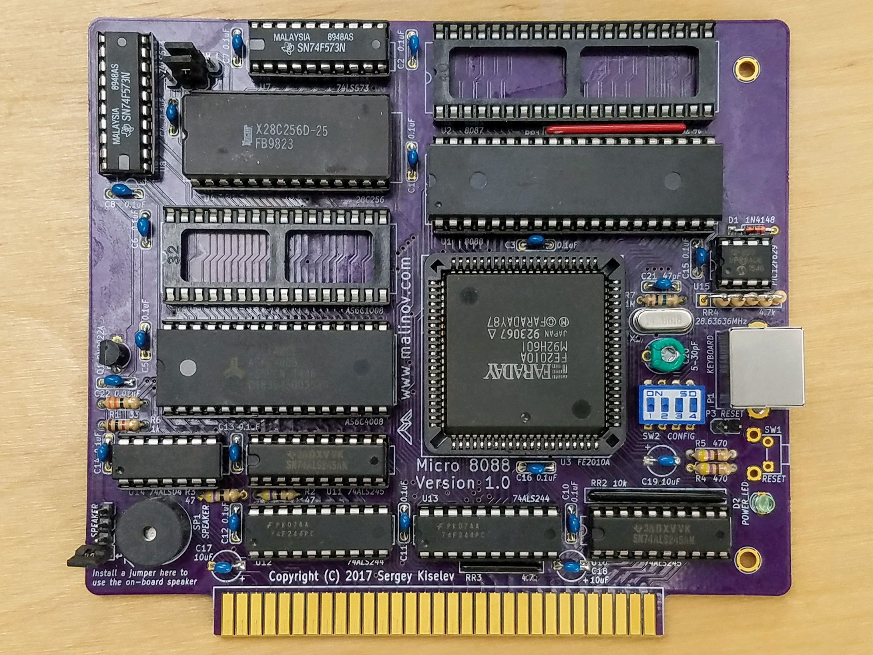
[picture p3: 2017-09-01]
images/Micro_8088_Assembled_Board-1.0.jpg

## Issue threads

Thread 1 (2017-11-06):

FE2010 Datasheet

crasbe, 2017-11-06:
Hey,

I don't know if you have found this yet, but here is the datasheet of the FE2010 from Faraday: https://www.tvsat.com.pl/pdf/f/fe2010_far.pdf (also attached).

This might give some insightes and also features a reference design.

Greetings,
Chris
[fe2010_far.pdf](https://github.com/skiselev/micro_8088/files/1446091/fe2010_far.pdf)

skiselev, 2017-11-06:
Hi Chris,

Thank you for contacting me!

I do have this datasheet. I probably should put it in the GitHub repository, together with the datasheets of other components used in this project.

I am looking for FE2010A datasheet. The closest I have is Intel Wildcard 88 datasheet. That module is apparently based on FE2010/FE2010A, and the datasheet documents some chipset registers. I also have schematic for Commodore PC10-III, which is also based on FE2010A.

Thanks,
Sergey

skiselev, 2017-11-25:
I've added the Faraday FE2010 datasheet into the repository - Documentation directory.

Closed 2017-11-25.

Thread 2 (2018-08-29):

Cannot locate FE2010

cbmeeks, 2018-08-29:
I really want to build this board.  But I cannot find a Faraday FE2010A (or similar) chip.  Maybe my eBay searching skills are failing me.  Do you happen to know of a place where I could buy one?

Thanks_

skiselev, 2018-08-29:
Here is one on [eBay](https://www.ebay.com/itm/1pcs-FE2010A-JU-FE2010-PLCC84-FARADAY/263277266243)
Also check Chinese distributors, e.g. [UtSource](https://www.utsource.net/)

cbmeeks, 2018-08-29:
I don't know how I missed that.

Thank you!

skiselev, 2018-08-29:
You're welcome! I am closing this issue.

Closed 2018-08-29.

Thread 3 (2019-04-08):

Missing Kicad Libraries

kwadwobro1, 2019-04-08:
Kicad complain with the error

The following libraries were not found:

74ls-sergey.lib

dallas-rtc.lib

devices-sergey.lib

intel-8xxx.lib

memory-sergey.lib

transistors.lib

conn.lib

linear.lib

regul.lib

cmos4000.lib

adc-dac.lib

memory.lib

xilinx.lib

special.lib

microcontrollers.lib

dsp.lib

microchip.lib

analog_switches.lib

motorola.lib

texas.lib

intel.lib

digital-audio.lib

philips.lib

display.lib

cypress.lib

siliconi.lib

opto.lib

atmel.lib

contrib.lib

valves.lib

when you open the project file in Kicad

skiselev, 2019-04-08:
I think you can safely delete these libraries. These were default libraries from an older KiCad version. All the custom components should be [my_kicad_library](https://github.com/skiselev/my_kicad_library) repository.
Please let me know if the schematic editor doesn't properly show components (run an ERC too).

Closed 2019-06-04.

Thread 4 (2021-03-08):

Tie pins 1 and 30 of U4 to ground in next revision?

KyleJ61782, 2021-03-08:
So I received a pre-built Micro 8088 except they put in an SST39SF040. Practically that's not really an issue because it appears they flashed 4 images onto it at 128K intervals, but the problem is that the BIOS writes settings back to flash which could be an issue because pins 30 (A17) and 1 (A18) are floating, so their values in theory could change. See the pin assignments from the data sheet:

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

I've already changed the BIOS settings write code to handle the larger flash, but to ensure the address lines aren't floating I'm just going to put in bodge wires tying them to ground, so it won't be a problem. Perhaps, though, connecting both pins to ground in the next revision opens up more substitution possibilities?

skiselev, 2021-03-08:
It makes sense. It also should support 29F020/39SF020 ICs in this case. By the way, do you mind contributing the flash programming code changes to the https://github.com/skiselev/8088_bios project?

KyleJ61782, 2021-03-08:
Absolutely! I'm working on a few things related to the BIOS at the moment and plan on submitting all of the code back. I'm working on the uflash code at the moment, enabling that to work with bigger chips as well.

prabathbr, 2023-06-26:
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

> It makes sense. It also should support 29F020/39SF020 ICs in this case. By the way, do you mind contributing the flash programming code changes to the https://github.com/skiselev/8088_bios project?

Hi, I ordered a "SST39SF020A-70-4C-PHE-ND" instead of SST39SF010A as it is backorder in Digikey. I though I can just ground PIN30 and use it. Would I need to do any other changes to the BIOS code ?

skiselev, 2023-11-08:
> Hi, I ordered a "SST39SF020A-70-4C-PHE-ND" instead of SST39SF010A as it is backorder in Digikey. I thought that I can just ground PIN30 and use it. Would I need to do any other changes to the BIOS code ?

The latest 8088 BIOS version supports SST39SF020A and SST39SF040 ICs

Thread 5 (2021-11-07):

Proton PT8010AF instead of Faraday FE2010A ?

explit7, 2021-11-07:
Hello Sergey.
This guy wrote here, that Proton PT8010AF is a clone of Faraday FE2010A.
http://dosdays.co.uk/topics/faraday_chipset.php

While its very difficult to find Faraday FE2010A. and the price tags are very high,
the Proton PT8010AF is cheap and can be purchased for adequate price on aliexpress:

https://www.aliexpress.com/item/1005002678888959.html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

Dp you have some information about this chip, could it be used as a direct replacement, or are software changes (eg. BIOS) needed?

Thanks
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

skiselev, 2021-11-08:
The information that Proton PT8010AF is possibly a clone of Faraday FE2010A is actually coming from me... But that's a good point. I have a motherboard based on Proton PT8010AF, and I can try to check the pinout and confirm if it is the same as Faraday FE2010A, also perhaps poke chipset registers and see if they are the same as FE2010A... Maybe later this week

skiselev, 2021-11-08:
I did a bit of reverse engineering on my Proton PT8010AF board, and I can confirm that the pinout is the same as that of Faraday FE2010A.
I haven't done any software testing yet. There might be some differences there. I've ordered some Proton PT8010AF ICs, and I'll test Micro 8088 when they arrive.

explit7, 2021-11-08:
Really cool, thanks, will also order one to test!

skiselev, 2021-11-18:
I received a Proton PT8010AF IC, and tested it on the Micro 8088 board.
It does work. Although, it appears that it inserts more wait states than Faraday FE2010A does, and as the result the system runs slightly slower. Not a significant difference, also when running on 9.55 MHz, it might be possible to reduce the number of the wait cycles by setting both bits 7 and 6 of the chip configuration register at port 0x63, which brings the performance to the same as FE2010A performance with only bit 7 set - the default turbo mode in my BIOS.

explit7, 2021-11-18:
thanks for the info, Sergey! this are indeed great news! That means for many - the search for the FE2010A is over, and PT8010AF could be bought for adequate precises!

explit7, 2021-11-18:
Should it means, that you need to change something in BIOS ?

skiselev, 2021-11-18:
It will work as is, just a bit slower than FE2010A. I am still checking if there is a way to detect PT8010A and adjust the configuration...

skiselev, 2021-11-21:
It appears that the slowness of PT8010AF vs. FE2010A is caused by DRAM refresh being enabled by default in PT8010AF, and disabled in FE2010A. I am not 100% certain what causes this difference. The BIOS does enable refresh on both.
I am planning to update the BIOS not to enable DRAM refresh. It is not needed anyway since Micro 8088 and related projects use SRAM instead of DRAM

eluancm, 2021-11-23:
Just FYI, utsource cancelled my order and asked for 3x the initial price, so it looks like this is going the FE2010A way fast.

skiselev, 2021-11-23:
@eluancm same happened to me.
It is quite possible that Utsource people (or their suppliers, since I don't think Utsource really stocks anything) read this or Twitter posts, or simply observe the demand, and adjust prices. They had some ICs laying around without anyone asking for them for 30 years, and suddenly the demand picked up. Well, another incentive for me to develop systems that don't rely on old/proprietary components.

skiselev, 2021-11-23:
The answer is "yes", Proton PT8010AF can be used instead of Faraday FE2010A, if you're lucky to find it.
Closing this ticket...

wrljet, 2021-11-23:
Mine says "departed shipping partner".  Ordered on 11/18.

I hope they aren't counterfeit/fake.

Bill

explit7, 2021-11-23:
mine came last week. got it for 17,- eur including shipping.

   On November 23, 2021 at 4:29 PM Bill Lewis ***@***.***> wrote:

    Mine says "departed shipping partner". Ordered on 11/18.
    I hope they aren't counterfeit/fake.
    Bill
    —You are receiving this because you authored the thread.Reply to this email directly, view it on GitHub, or unsubscribe.Triage notifications on the go with GitHub Mobile for iOS or Android.

wrljet, 2021-12-01:
Mine arrived 30 Nov.  Ordered on 18 Nov.

Closed 2021-11-23.

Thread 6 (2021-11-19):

Mouser BOM has several issues that need to be corrected

hexbus, 2021-11-19:
11 items have minimum order quantities of 2000 and need to be updated as of November 2021.

There are also several SKUs that are obsolete and some unavailable.  These will have to be substituted or ordered elsewhere.

Also, there are about four backordered, likely due to the chip shortage, and will need to be procured elsewhere.

skiselev, 2021-11-19:
Not sure if it is a "bug" per se. The components availability changes and it is difficult for me to maintain an up to date BOM. I treat it more as a list of suggested components. Next time, if you like, consider contributing - fix the issue and create a pull request.
Nevertheless, I've updated the BOM with components that are commonly available from Mouser in single quantities. I also replaced DIP sockets with Amphenol ones, that are very similar to previous 3M sockets, but a bit cheaper.
Note that there is still one component in the BOM - trimmer capacitor, which is not available from Mouser. I've added a note to the BOM saying that it is optional and can be replaced with a regular ceramic capacitor
Also there are 5 components that are backordered. I believe for most of them there are alternatives available, so just look around:
* 4606X-101-472LF resistor array can be replaced with 4606X-AP1-472LF which is exactly the same part, but in "ammo-pak" instead of bulk pack
* There are at least two available alternatives for PN2222A transistor, and that can be also replaced with other NPN BJT transistors, such as 2N3904
* Instead of the LTL-4231NHBP LED indicator with housing, a regular 3 mm LED can be used
* Instead of the currently unavailable 5 position DIP switch, any other 5 position DIP switch can be used
* Finally, instead of the CP80C88-2Z CPU, any other 8-10 MHz 8088, 80C88, one NEC V20 CPU can be used.

Closed 2021-11-20.

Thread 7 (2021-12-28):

Updated link for AT2XT Firmware

prabathbr, 2021-12-28:
The given links in the README.md for "AT2XT Firmware" is dead due to forum upgrade.
New link for the post containing "XTATKEY_094.zip" is :

https://forum.vcfed.org/index.php?threads/at-to-xt-keyboard-converter.16050/post-304769

skiselev, 2021-12-28:
Thank you for reporting this broken link!
I've updated the README.

prabathbr, 2023-06-21:
Hi, I also found below link where it is available to download without registering in a forum.
I haven't personally used this though.

https://hackaday.io/project/166433-at2xt-keyboard-adapter

Closed 2021-12-28.

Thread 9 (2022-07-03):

Missing a reset pull-up resistor

andykarpov, 2022-07-03:
FE2010A datasheet says that the reset line should be equipped with a 10k pull-up resistor, that is missing on the current design.
Adding that 10k pull-up increased stability of the board's power-up and reset.

P.S. Also i've added a 47k resistor in parallel of the 10uF reset capacitor to discharge it after power-off, so it can produce a proper initial reset signal for the next power-on cycle.

skiselev, 2022-07-03:
/RESIN has a pull-up resistor (RR2).
I don't think CLEAR/RESET should have one.
It could be a good idea to connect a diode between /RESIN and VCC to discharge it when system is powered down

andykarpov, 2022-07-03:
Ah, yes, thanks, i see, and sorry about the invalid issue then :)
Regarding the discharging diode - well, nice idea, let's try!

Closed 2023-02-01.

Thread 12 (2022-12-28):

Can't write Flash, nor FDD

TzOk83, 2022-12-28:
After some minor issues, I've managed to start Micro8088, but I have 2 problems:
1. I can't store BIOS Setup settings in Flash.
2. I can't write anything to FDD.

ad. 1. When I try to save settings in BIOS setup, I got ERROR, and it continues to boot. I have SST 39SF020 Flash chip on board, with pins 1 and 30 tied to GND.

ad. 2. When I try to write anything to floppy (to be more accurate to GOTEK/Flash Floppy FDD emulator) the computer hangs. I've tried two different FDD controllers (one I'm using now is a PTI227W Multi I/O 16-bit ISA card based on W83757F+W83758P).

Don't know if this has anything to do with the issue, but the computer is hard to boot. After powering on, it often freezes, with no activity on the bus. The other small issue was, my 28.6363 MHz crystal was oscillating at 1/3 of that frequency - the computer was running, but very slow. Now I've put 14.3 MHz taken out of some scrapped modern motherboard (from the LPC bus), and it runs fine.

When I try to run BASICA from PC-DOS 3.30 I get "Divide overflow" error.

I was unable to get the recommended Faraday chipset, so I'm using a Proton clone. CPU is NEC V20 (I also have tried the original i8088), and all "TTL" chips are 74HCT series (it is really hard to get anything else).

Except for those issues, the computer seems to run fine and stable.

What I can/should check to resolve that issues? I have a simple logic and a 4 channel DSO.

skiselev, 2022-12-28:
Your issue documents multiple problems. Next time please submit separate issues. It will make it easier for me to address, and for others, who encounter similar issues, to find the discussion.

1. Two possible issues here: (1) You are not using U16 SPLD, instead you use U14 74*04 logic IC. In this case, the system will not support writing to the Flash ROM. (2) Support for SST39SF020 was just recently added to 8088 BIOS, and it is not a part of the image published in this GitHub repo. Please clone or download the source from [Micro 8088 GitHub repo ](https://github.com/skiselev/8088_bios)
2. Multiple things here again. (A) It is still not clear to me what frequency you're using. The FE2010A can work with either 28.63636 MHz or 14.31818 MHz crystals. I am not sure if the Proton PT8010AF supports 14.31818 MHz frequency. In any case, if using 14.31818 MHz crystal, make sure that JP2 XSEL jumper is open. Wrong (too low) frequency might be one of the reasons the FDC does not work properly, or create stability issues. Measure the actual CPU frequency (CLK signal on the CPU). Ultimately, I recommend getting the 28.63636 MHz crystal documented in the BOM, or a crystal with very similar characteristics (B) BASICA will not work on Micro 8088, or for that matter on any IBM PC clone, because it requires built-in ROM BASIC, which was only provided with the original IBM computers. Use GWBASIC instead (C) I do not recommend using 74HCT series, they do not provide enough current to drive ISA bus. Use 74F series, or if you cannot find them, try 74LS or 74ALS (they are not guaranteed to work, but better chances than with 74HCT).

TzOk83, 2022-12-29:
Sorry for 2 issues in one post, but I believed, they are connected with each other.

ad. 1. I'm using SPLD. I thought it was enough to hold additional address lines low, but it is apparently not, so I'll try to compile BIOS from source.

ad. 2. I'm using 14.3 MHz crystal and JP2 is open. Both clocks present on ISA bus have correct frequencies and look ok. 74HCT have way higher output current capabilities than LS (25 mA vs 8 mA), yet they are slightly slower (22 ns vs 15 ns). I'm trying to locally source either LS or F series chips, but without any luck. Reference design from Faraday is using LS chips as well as my ISA cards do.

TzOk83, 2022-12-29:
I can close this issue, as compiling BIOS from the most recent source solved writing settings to Flash, and FDD issues were completely my fault, unrelated to the hardware.

Closed 2022-12-29.

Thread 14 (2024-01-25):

Board boots only after press reset button

subzero2379, 2024-01-25:
If i cold boot no post ,if i press reset board boots,how board manages reset on cold boot is capacitor 10uf?

skiselev, 2024-01-25:
The C20 capacitor is indeed 10 uF. I don't have the same issue, and it is the first time I hear about such a problem.
It is possible that your power supply ramps up voltages too slowly.
Is this issue reproduceable with a different power supply?

subzero2379, 2024-01-26:
Ok resolved recapped my psu teo capacitors leaking
And boots fine

skiselev, 2024-01-26:
Good to hear!

Closed 2024-01-26.

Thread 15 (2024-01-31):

Strange Problems with Proton PT810AF

explit7, 2024-01-31:
Hello collegues.
I have a great, fully working Micro8088 Version 1.3 with NEC V20 and Faraday / WD FE2010A.

Now i have build another Micro8088 Board (Version 1.1). My Problem is, that both boards works without any problems with the FE2010A but if i put PT810AF instead - i see the BIOS screen, and the board immediately resets.
Sometimes the reset is very quick, sometimes, i see full BIOS screen.

This is the second Proton PT810AF which i bought at Aliexpress from China. From 2 different sellers. And both chips show the same problems which are not there with Faraday FE2010A.

Maybe its a defective stock of Proton PT810AF Chips?

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

skiselev, 2024-01-31:
One of my Micro 8088 currently has the Proton PT8010AF controller. It works just fine. That one particularly says "JAPAN" on it some place.
I have a few more Proton PT8010AF from a different batch, with a different marking. I don't think I tested them yet, I'll give them a try.

In your case, are these two PT8010AF from different sellers parked similarly? Maybe you can do a side to side photo from top and the bottom?
Another idea: check the "Fast wait states" setting. Maybe disabling wait states changes the behavior?

explit7, 2024-01-31:
Thanks for the info, Sergey, The 2x PT810AF has the same marking and was packed similar. So i think 2 different sellers shipped the PT810AF from the same batch. I flashed a new BIOS, so the frequency settings and wait state settings are default. Will try to put FE2010A and disable wait states manually (just to be sure).

At the moment i think that the full batch is somehow defective.

skiselev, 2024-02-01:
I tested PT8010AF from the other batch I have, and it works just as well as one that I had in the system.
The one which I normally have in the system is in the middle, and the new one is on the right.

Maybe there is something else going on? For example, power supply is not stable, which somehow affects the PT8010AF more than FE2010A?

Here are the photos for your reference:
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

explit7, 2024-02-01:
My Proton looks the same way like your on the right side. All AliExpress PT8210AF look this way.
The Proton in the middle seems to be an original Japan-made one.

I am very curious, because all who has Micro8088 Boards here in Germany, bought Proton PT8210AF in China on AliExpress, and they works just fine.

I think the whole batch of this chips may be defective, because with WD FE201A the same board is working absolutely fine.

The last thing, what i want to test is 8088 CPU instead NEC V20.

This is my other Micro8088 Mainboard Version 1.3 which is also working fine with FE201A
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

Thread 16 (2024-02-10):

3D printed bracket for micro_8088

giobbino, 2024-02-10:
Hi,
I've noticed the bracket I designed for the XT-IDE card fits perfectly in the micro_8088 card too.

This is the link to get it:

https://www.thingiverse.com/thing:6468509

Cheers,
Giovi

giobbino, 2024-02-12:
I didn't test the version without pins but should be OK

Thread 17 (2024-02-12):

"himem.sys requires an 80x86-based machine" error

giobbino, 2024-02-12:
hello,

I've build the card using SPLD, jp3 and jp4 open, sw3.2 / sw3.4 / sw3.5 =ON, sw3.1 and sw3.3 = OFF (sw3.3 must be off or it won't detect the XT-IDE).

I'm using your VGA and FDD cards and XT-IDE (plus an AdLib clone based on your audio card project).
Everything seems to work perfectly, I tried a couple of ms-dos games: they works great.

I tried to add the following sentence to the config.sys (MS-DOS 6.22)
device=c:\dos\himem.sys dos=high, umb

but it returns this error:
_himem.sys requires an 80x86-based machine
XMS driver not installed._

I digged a little into Google (have to admit I don't remember much about MS-DOS on 8088 systems) and I've found himem.sys requires at least 286.

But how I can use the UMB memory from MS-DOS ?

Closed 2024-02-22.

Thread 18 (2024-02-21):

clock speed setup by keyboard doesn't work

giobbino, 2024-02-21:
Hi,
not a big issue, but...

the Ctrl-Alt-Keypad -/+/* sequence doesn't work (at least for me). I checked the speed with the speed.com program and there is no difference at all.

Just to be sure, I tried to modify the clock speed by the Bios, and the speed.com routine correctly shows the different frequency.

skiselev, 2024-02-21:
What platform are you using?
It will not work on Book8088 because turbo there is not software controllable

giobbino, 2024-02-21:
micro_8088

giobbino, 2024-02-21:
I suspected it, so I already did that test before to open the issue, trying to modify the speed from the dos prompt. It doesn't change. I tried many times, i.e. boot (BIOS says 9.45 MHz) -> prompt ms-dos -> press Ctrl/Alt/-  -> speed.com -> nothing changes.

Just a question: should this function modify the BIOS value too? Because I did that test too, booting and then trying to modify the speed from dos prompt, by keyboard, and then reboot. No changes at all.

I also suspected the keyboard, so I tried with another one, different model. Nope.

skiselev, 2024-02-22:
I [tested it and it works for me](https://youtu.be/vTrLP7aXUKg?si=SCVkONw-54LqYj1T).
Maybe it has to do with the "Pass E0 code" switch (SW2.3)? What's the current setting of that switch in your system?

giobbino, 2024-02-22:
It was OFF, but I tried to put it to ON, no changes. Just to be sure, I downloaded the same tool you're using, systest, and tried both switch modes.  The single keys off the keyboard (ctrl, alt, keypad +, - , *) are working.

BTW I believe it doesn't any difference, but today I discovered I did a mistake while mounting the backplane, I put all caps 10 uF, but I've seen the C20 is 1 uF.  If you think it could make any difference, I'm assembling a 2nd micro_8088, this time with the right cap. It will take a day or two yet...

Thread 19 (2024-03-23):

3D print full desktop cabinet for 8088 oh thingiverse

giobbino, 2024-03-23:
Hello,
I released a project for a full desktop cabinet (CPU, PSU, Floppy disk drive) for the micro_8088 computer. I made it suitable for the Creality Ender 3 Pro, so it should be ok for most printers (it requires a printer with at least 220x220 mm print size).

https://www.thingiverse.com/thing:6546330

There are two flavors, a smaller one that will fit perfectly the micro_8088 and all the Sergey's cards, and a bigger one that can also host the LPT + COM card by hkzlab.

Hope this would help!

- Giovi

lpsantil, 2024-03-23:
You might also be interested in this AT/386/486 style case.

https://www.vogons.org/viewtopic.php?f=46&t=85634&start=20

CodeAsm, 2024-03-27:
> You might also be interested in this AT/386/486 style case.
>
> https://www.vogons.org/viewtopic.php?f=46&t=85634&start=20

So much plastic, but that vogons thread case looks awesome. maybe a metal behind and im happy. both cool projects tho, cause not everyone can bend metal or dares to touch sharp metal

giobbino, 2024-03-27:
Indeed, the 386/486 case is great... much, much better than mine. Unfortunately you need at least a 300x300 mm bed, so you can't print it with an entry-level printer like the Ender 3 and so on. Maybe when I will change my Ender 3 with a bigger one - I'm also waiting for the Sergey's 386 project  ;-)

I'm not actually concerned about how much filament I use, it's quite cheap _(especially if compared with the micro_8088 budget - all the PCB cards and backplane, the needed components, the PSU, etc.)_ ; so I decided to make a strong case. Using a 10-20% infill, you can print everything with less than a filament spool.

Also, for an XT-clone, I prefer the desktop model, with a monitor on top of it (I'm using an 8" LCD display, 4:3, I bought on Aliexpress with a 3D-printed case), instead the tower model.

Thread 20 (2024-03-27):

Broken link for AT2XT PIC12F629 firmware

wrljet, 2024-03-27:
In the building instructions:

**7. Program the PIC12F629 microcontroller with the** [AT2XT Firmware](https://github.com/skiselev/micro_8088/blob/master/www.vcfed.org/forum/showthread.php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)

The link doesn't work anymore.

Perhaps [this is the correct link?](https://forum.vcfed.org/index.php?threads/at2xt-keyboard-converter.26861/post-1242916)

Bill

skiselev, 2024-04-18:
Bill, thank you for reporting it!
Fixed here: https://github.com/skiselev/micro_8088/commit/74707ecbe01a6988f483716e44d132f57d15f9d2

Closed 2024-04-18.

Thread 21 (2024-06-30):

CGA Cards works only after reset or second PowerOn in Micro8088

explit7, 2024-06-30:
Hello @skiselev and other collegues! I have a strange issue with CGA Cards on Micro8088. Doesnt Matter ift it is a Cycle Logic CGA or Graphics Gremlin Card, it works only after second PowerOn cycle or reset.

If i switch Micro8088 for the first time - i have garbage on the screen (Cycle Logic CGA Card) or constant Graphics Gremlin Test Pattern (Graphics Gremlin 1) which stays static. The computer boots in the background, but the screen stays static.

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

Thats very strange, in another XT Mainboard (TripleD TD-20) both cards works without any issues.
VGA Card works also without any problems in Micro8088.

The CGA Card occupies the next ISA Slot after Micro8088 Board, in another Slots it the same issue.
Could it be timing issue, that the CGA Card need more time to initialize?

I have following cards in My Micro8088 System:

- Lo-Tech XTIDE
- Adlib Gold Replica
- Micro8088 Mainboard
- Graphics Gremlin
- Boca I/O Card 2x COM, 1xLPT
- RTC8088 3.0

Any ideas, where this problem is coming from?

Update:
Here seems to be the same issue:
https://www.andavno.com/?p=248

explit7, 2024-07-01:
Close, as opened in the wrong Repo. It belongs to the 8088_bios Repo.

Closed 2024-07-01.

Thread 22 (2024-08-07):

Is there any chance for a similar mobo supporting 286/386 CPUs?

pshirshov, 2024-08-07:
Just re-posting my question from NuXT issue tracker: https://github.com/monotech/NuXT/issues/13

I would love to see a similar motherboard supporting 286/386 CPUs. Is there any chance for that?

explit7, 2024-12-08:
IMHO there will be a problem to fine Chipset Chips for 286/386. The goal of Micro8088 is that it based on a single FE2010(A) or 8210 chip. As i know, there are now 286/386 single chips Mainboard which can be easy soldered. There exist very small 386 Mainboard based on a single chip, but its very difficult to find this chip and to solder it.

pshirshov, 2025-01-11:
I'm surprised it might be the case, I believe that 386 had extremely wide adoption in various industrial applications and was manufactured until recently. It's definitely the case for 286, I'm wondering if a cheap FPGA might be used to replicate the relevant chips.

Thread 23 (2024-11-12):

Pc works but when load dos no scroll on c: no on screen what im typing if i type dir commands wirk but cant see what i erite on screen if run fdisk and escape cursor turns to normal

subzero2379, 2024-11-12:

skiselev, 2024-11-12:
A bit difficult to understand what's going on there. It seems like you're having display issues.
It would be nice to get a screenshot, a photo, or a video showing the issue, as well as a full description of your configuration, for example the type of the display/graphics card, type of the display.
Also, as troubleshooting steps, you can try to isolate the issue... Does it still happen if you use another display. Does your graphics card and display work with another system?

Generally speaking, the Micro 8088 and 8088 BIOS doesn't have much to do with the display, unless it is an MDA or a CGA display. In case of a EGA or a VGA/SVGA displays, the graphics card has its own BIOS extension.

It is also possible that newer LCD displays do not properly support some older VGA modes, and you are not seeing the top or the bottom of the image...

subzero2379, 2024-11-13:
you are right its a vga bios problemm
i will try to burn a later rom and see what happens

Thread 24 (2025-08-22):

Pull-up resistors of ISA bus

hightower70, 2025-08-22:
I would recommend adding pull-up resistors to some of the ISA bus signals. Most notably the IORDY signal, as it doesn't work reliably without it. It seems the FE2010 has no internal resistors. I would also recommend adding a pull-up resistor to the IRQ and DRQ lines, as the original XT board has these resistors. Other than that, the motherboard is a great job.

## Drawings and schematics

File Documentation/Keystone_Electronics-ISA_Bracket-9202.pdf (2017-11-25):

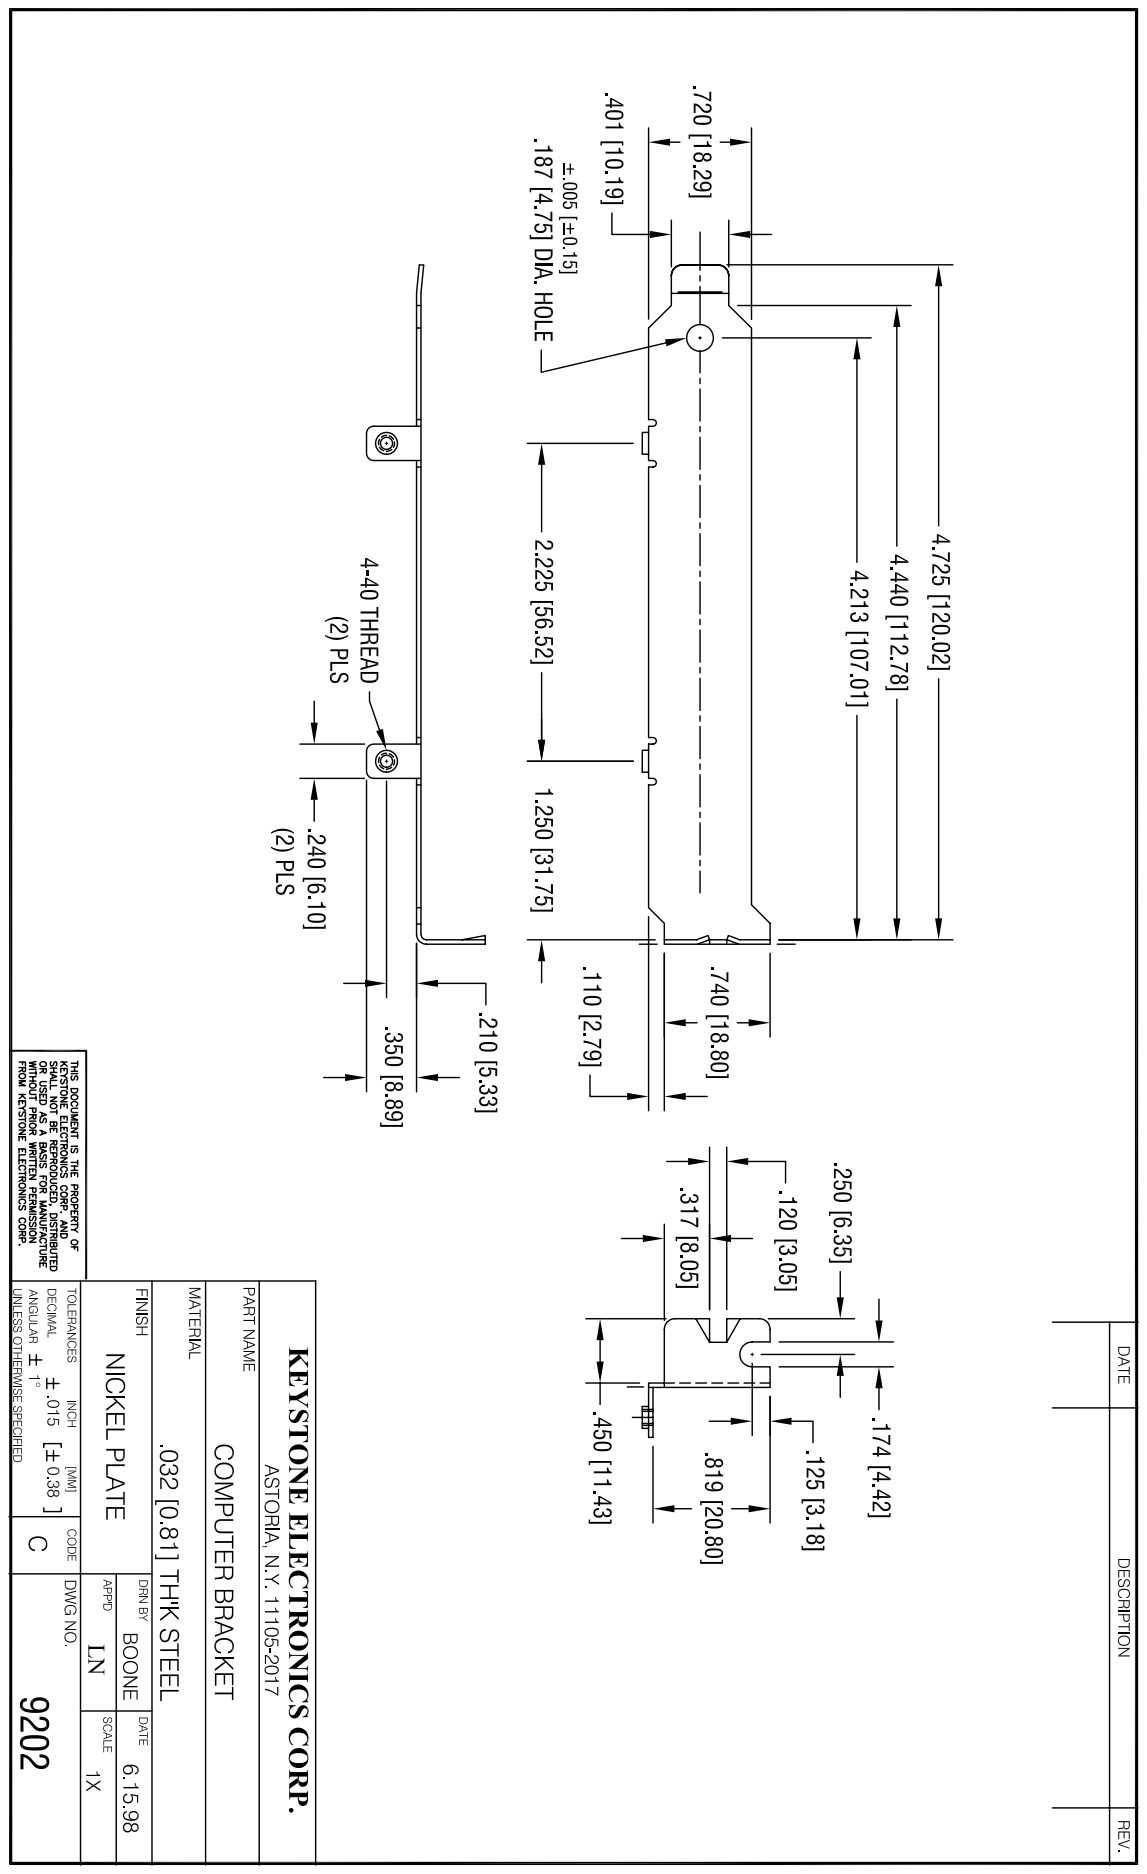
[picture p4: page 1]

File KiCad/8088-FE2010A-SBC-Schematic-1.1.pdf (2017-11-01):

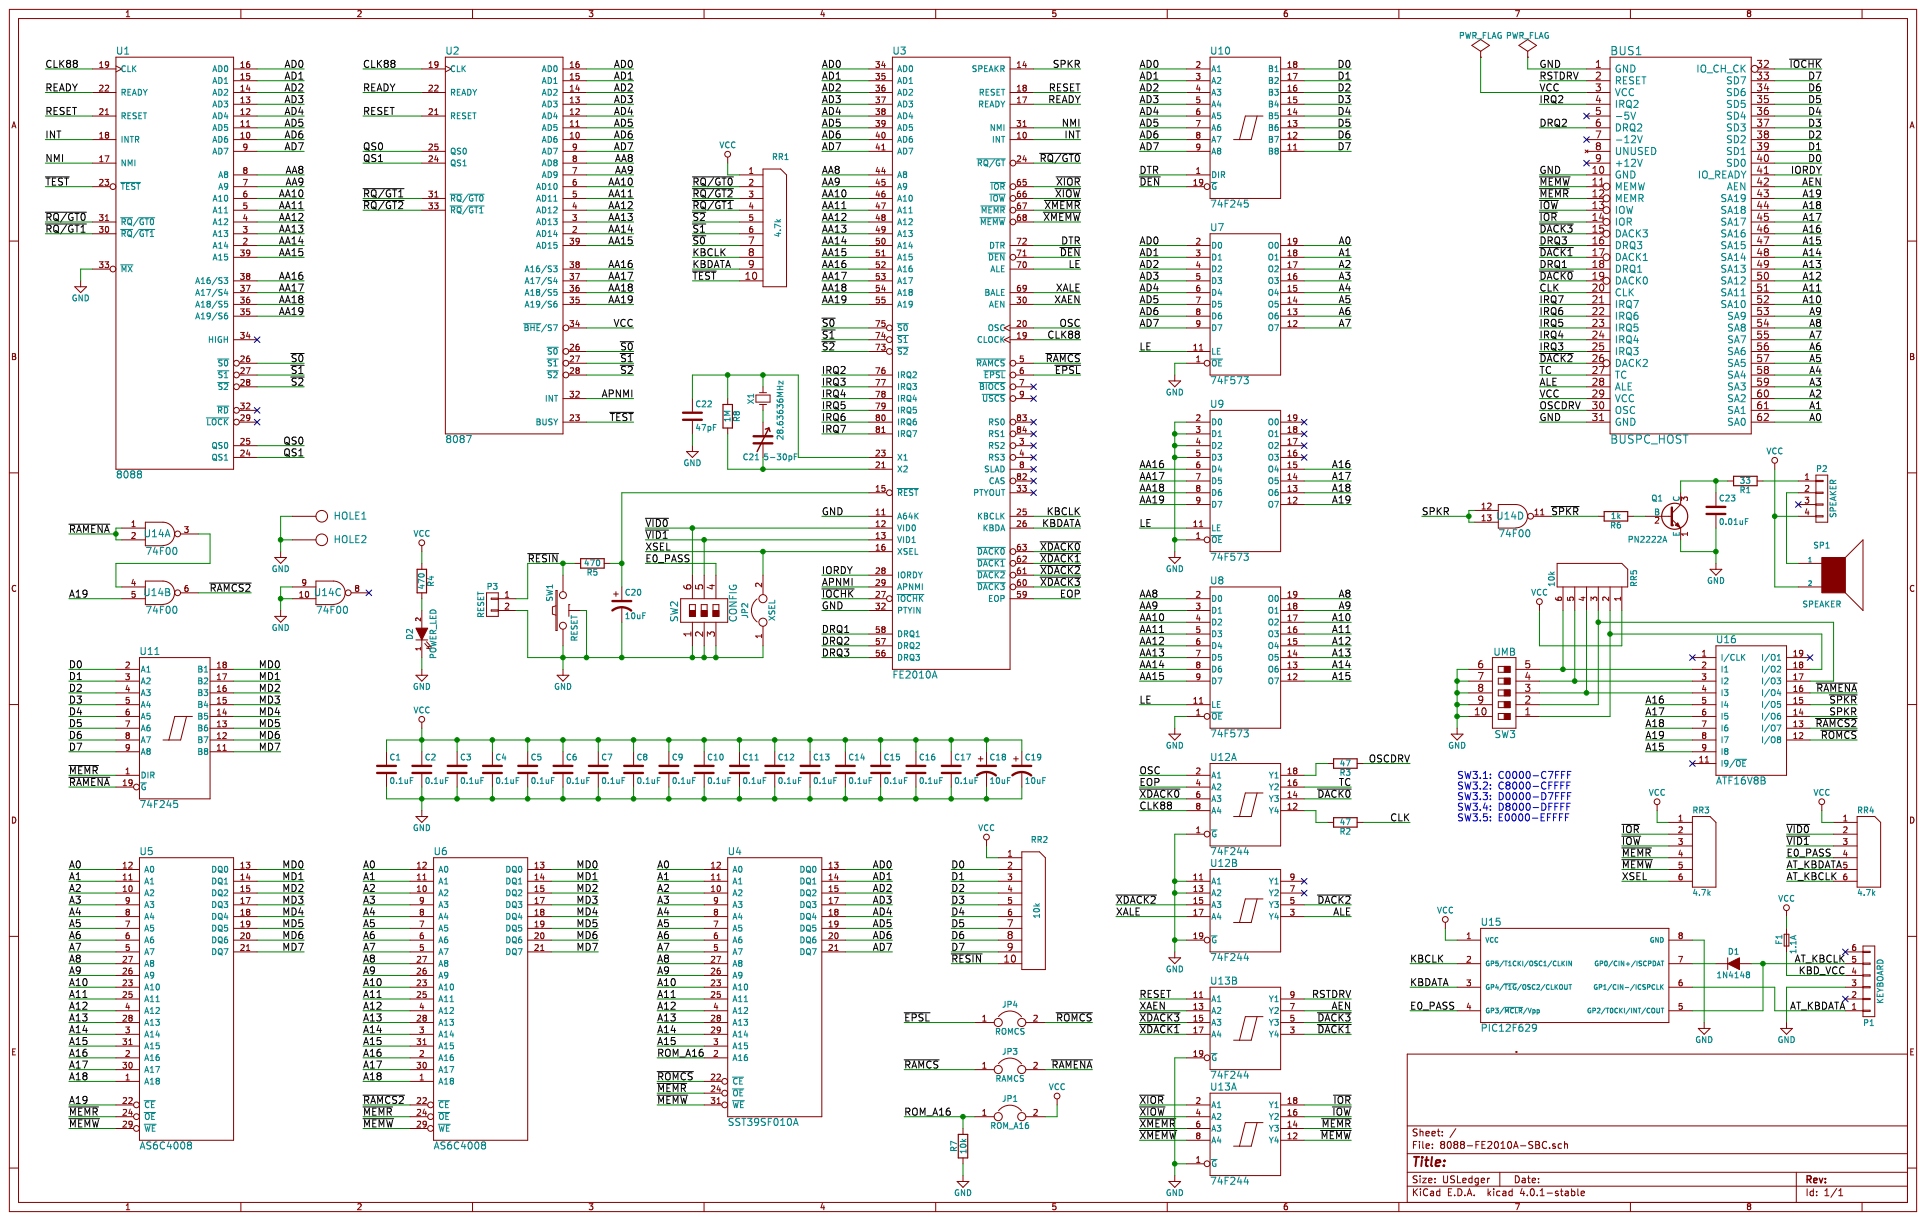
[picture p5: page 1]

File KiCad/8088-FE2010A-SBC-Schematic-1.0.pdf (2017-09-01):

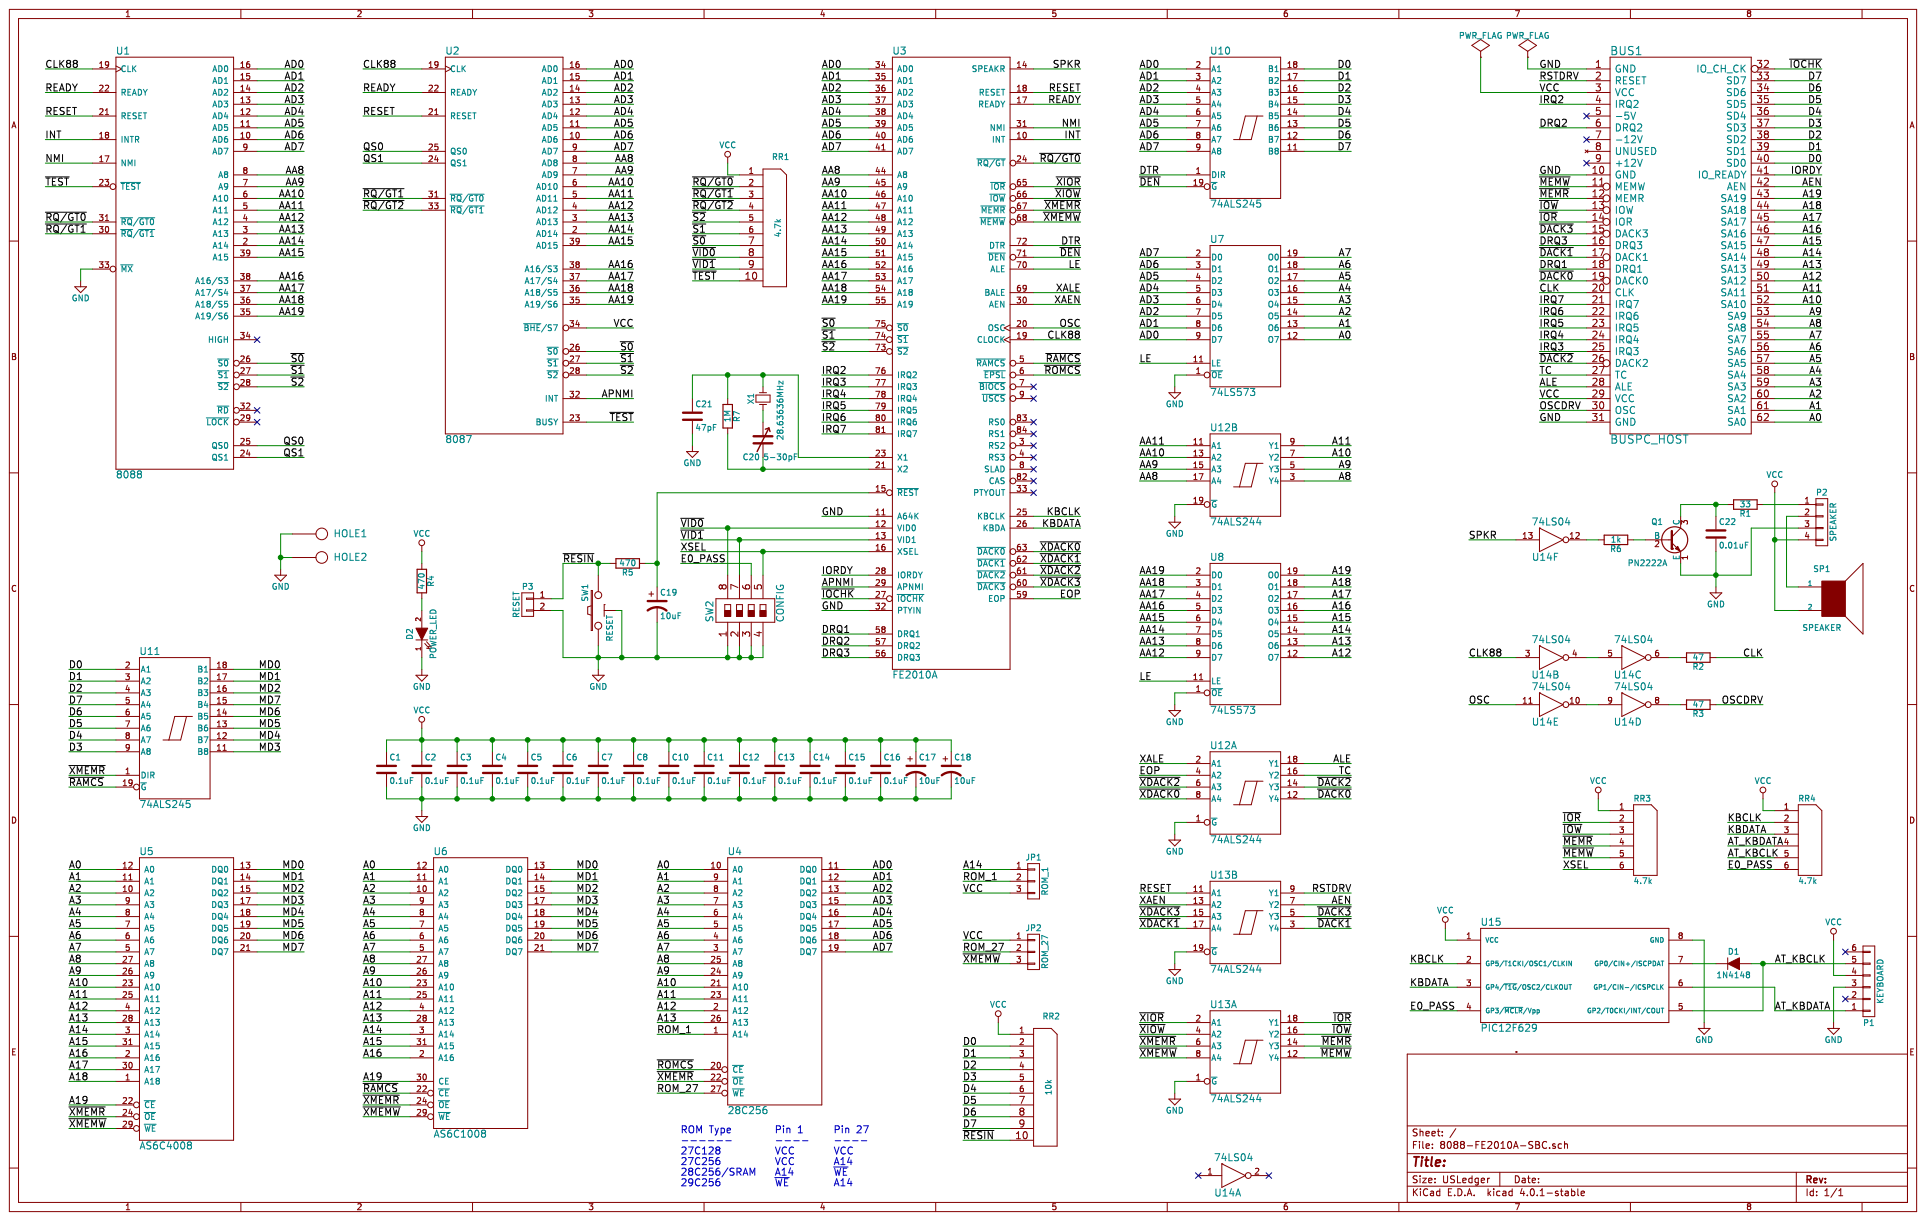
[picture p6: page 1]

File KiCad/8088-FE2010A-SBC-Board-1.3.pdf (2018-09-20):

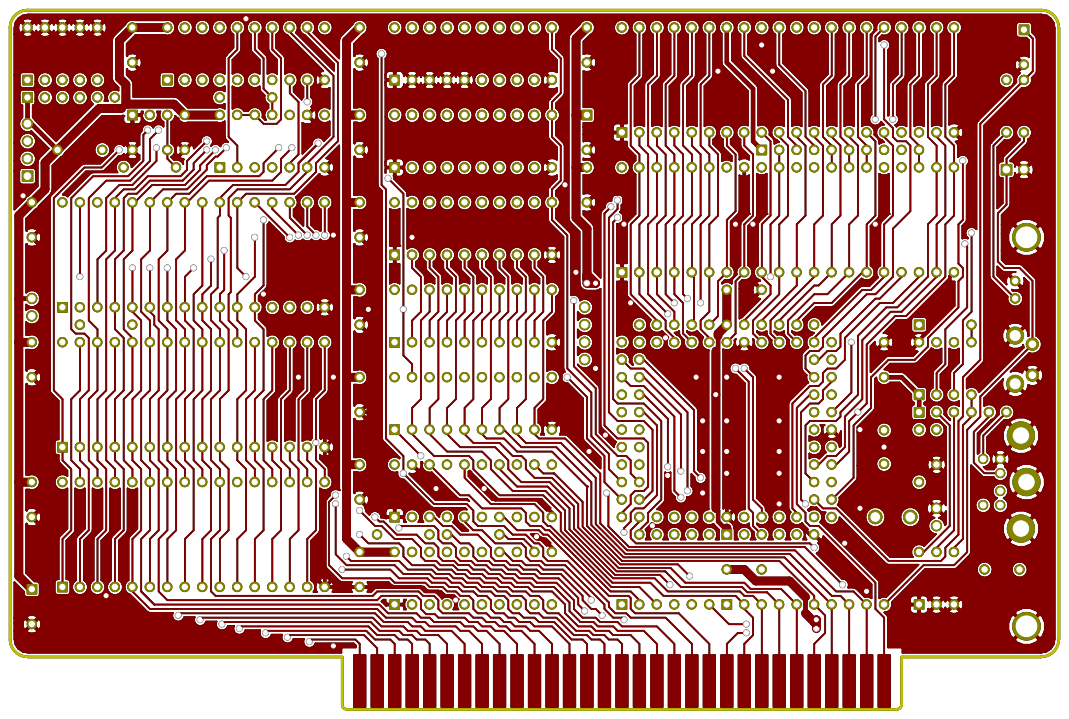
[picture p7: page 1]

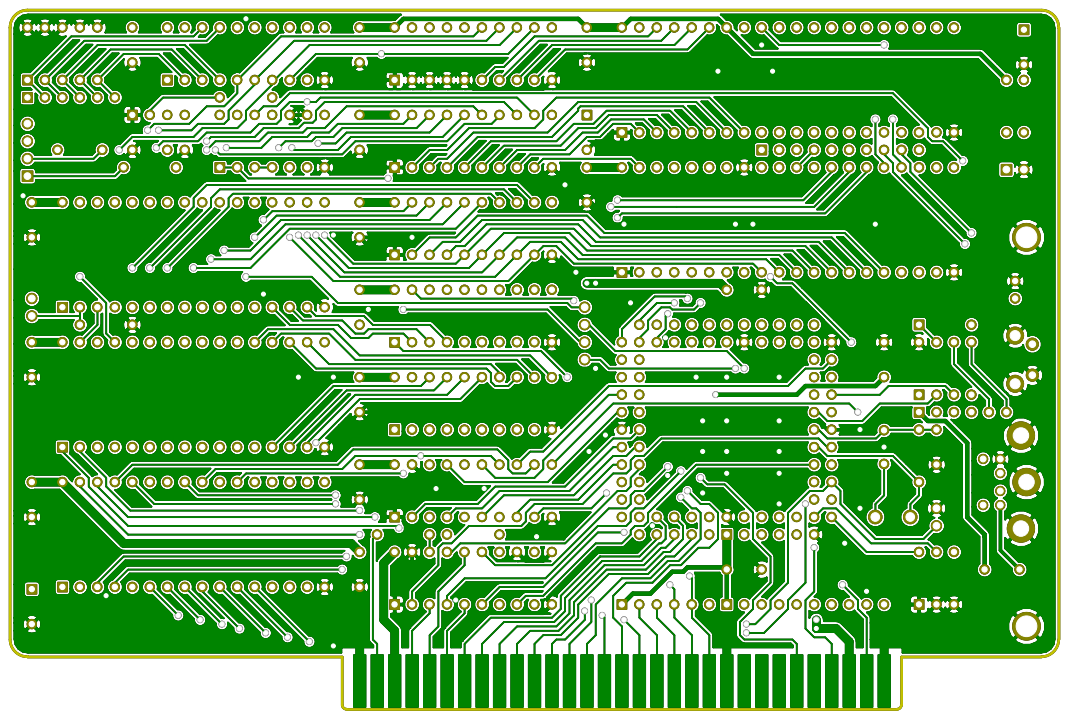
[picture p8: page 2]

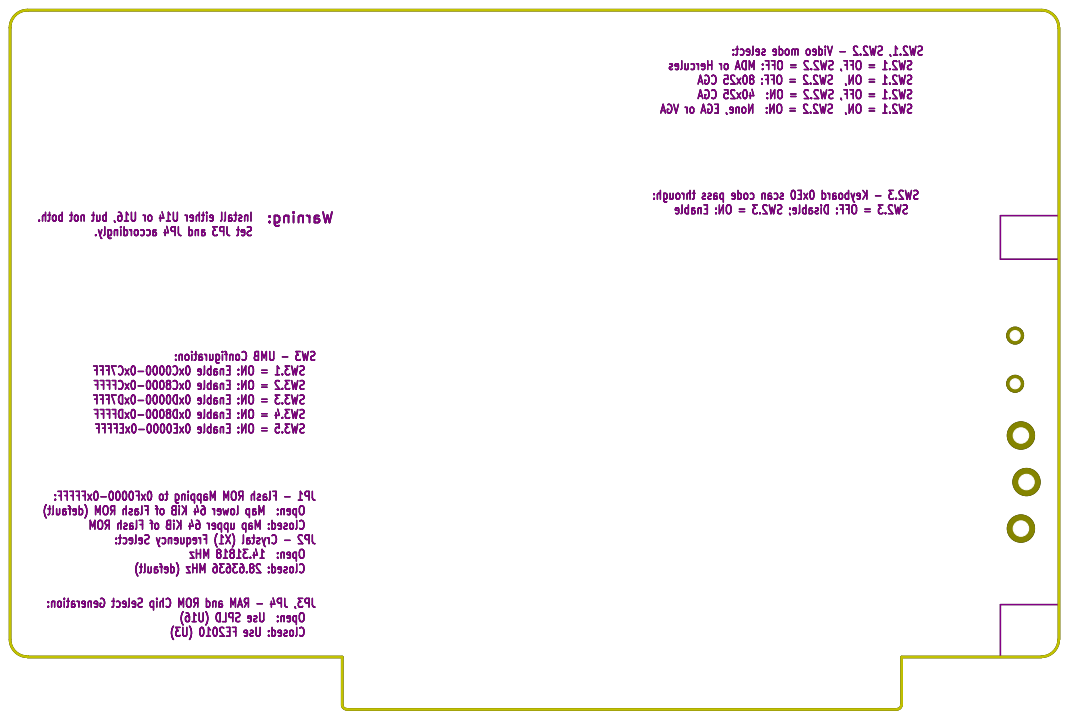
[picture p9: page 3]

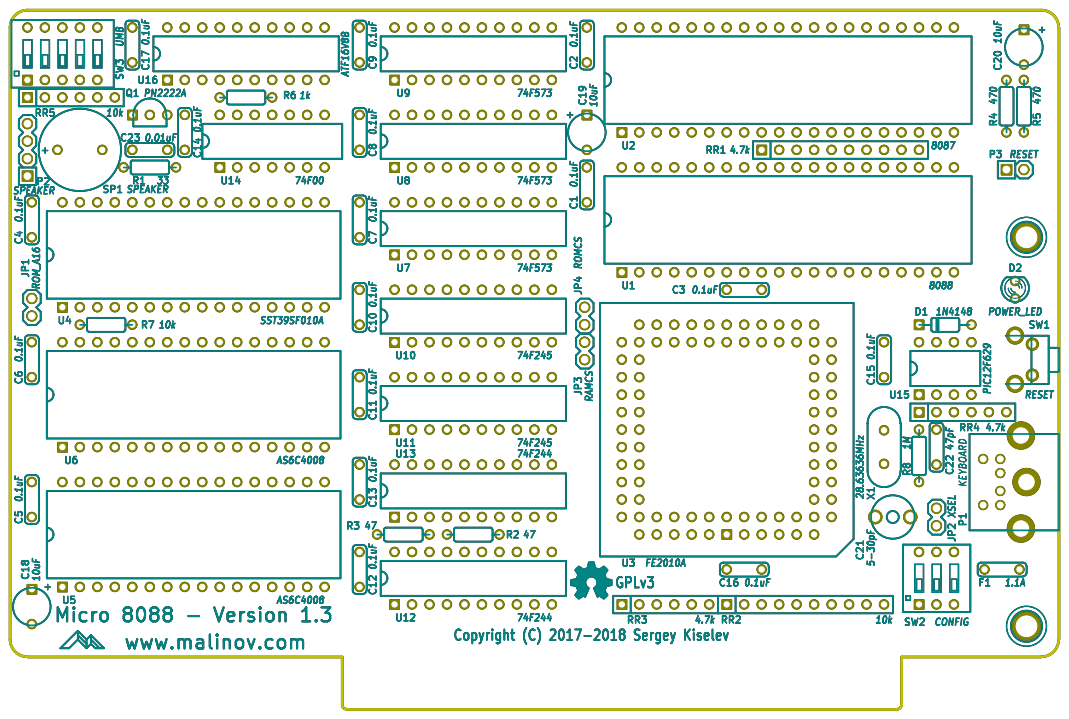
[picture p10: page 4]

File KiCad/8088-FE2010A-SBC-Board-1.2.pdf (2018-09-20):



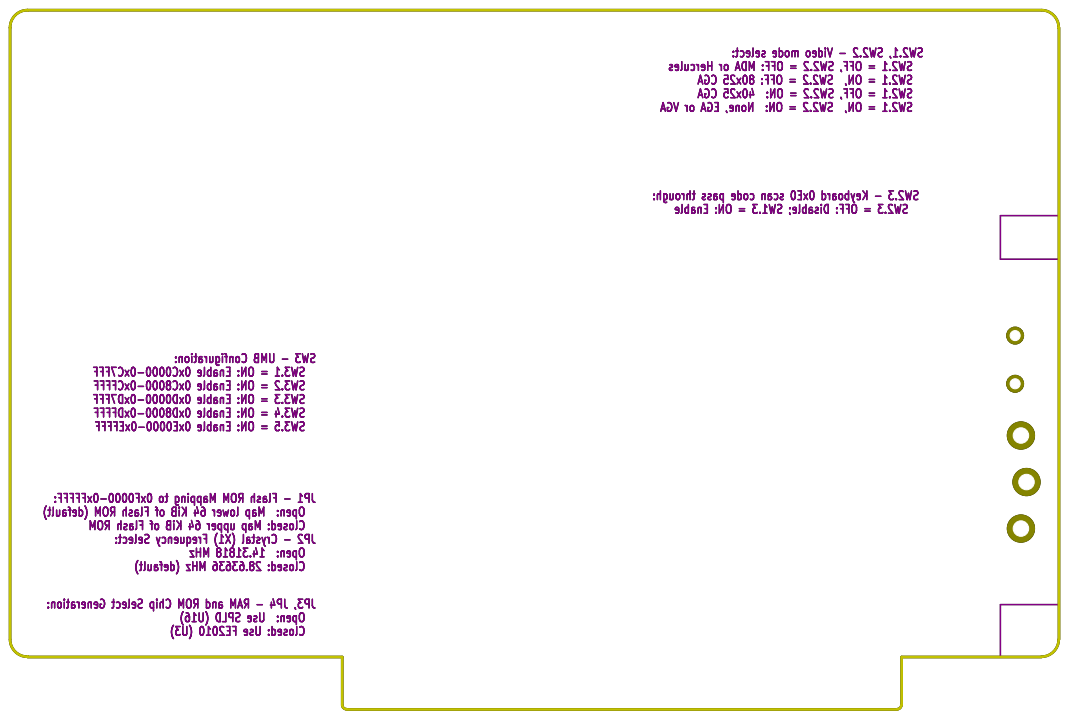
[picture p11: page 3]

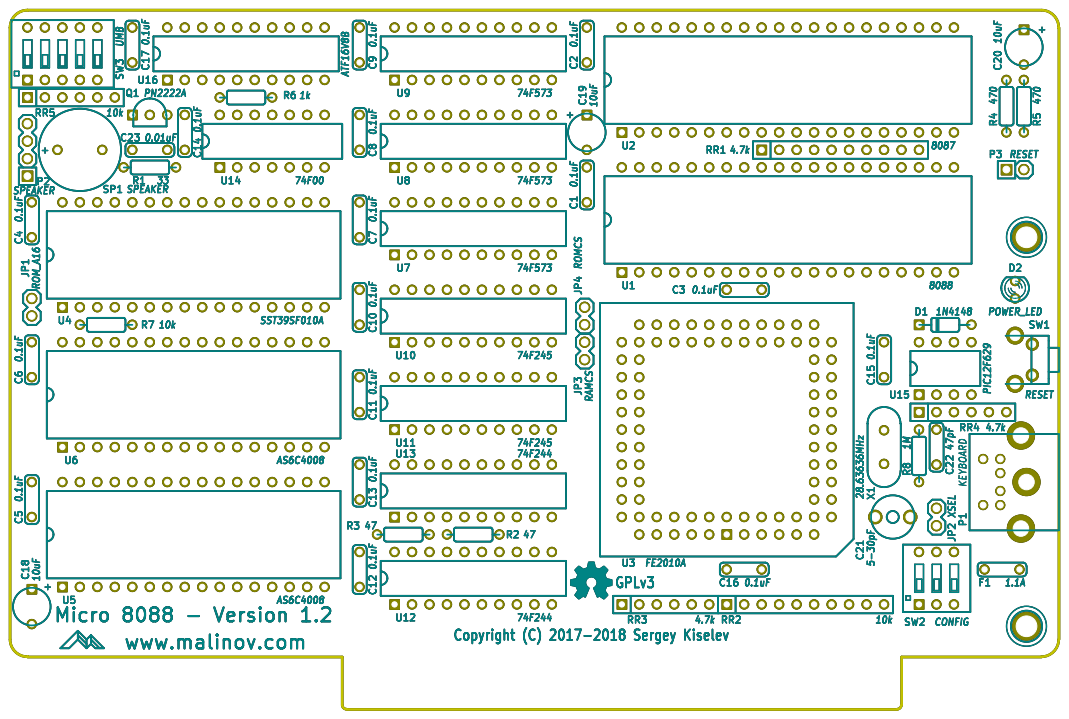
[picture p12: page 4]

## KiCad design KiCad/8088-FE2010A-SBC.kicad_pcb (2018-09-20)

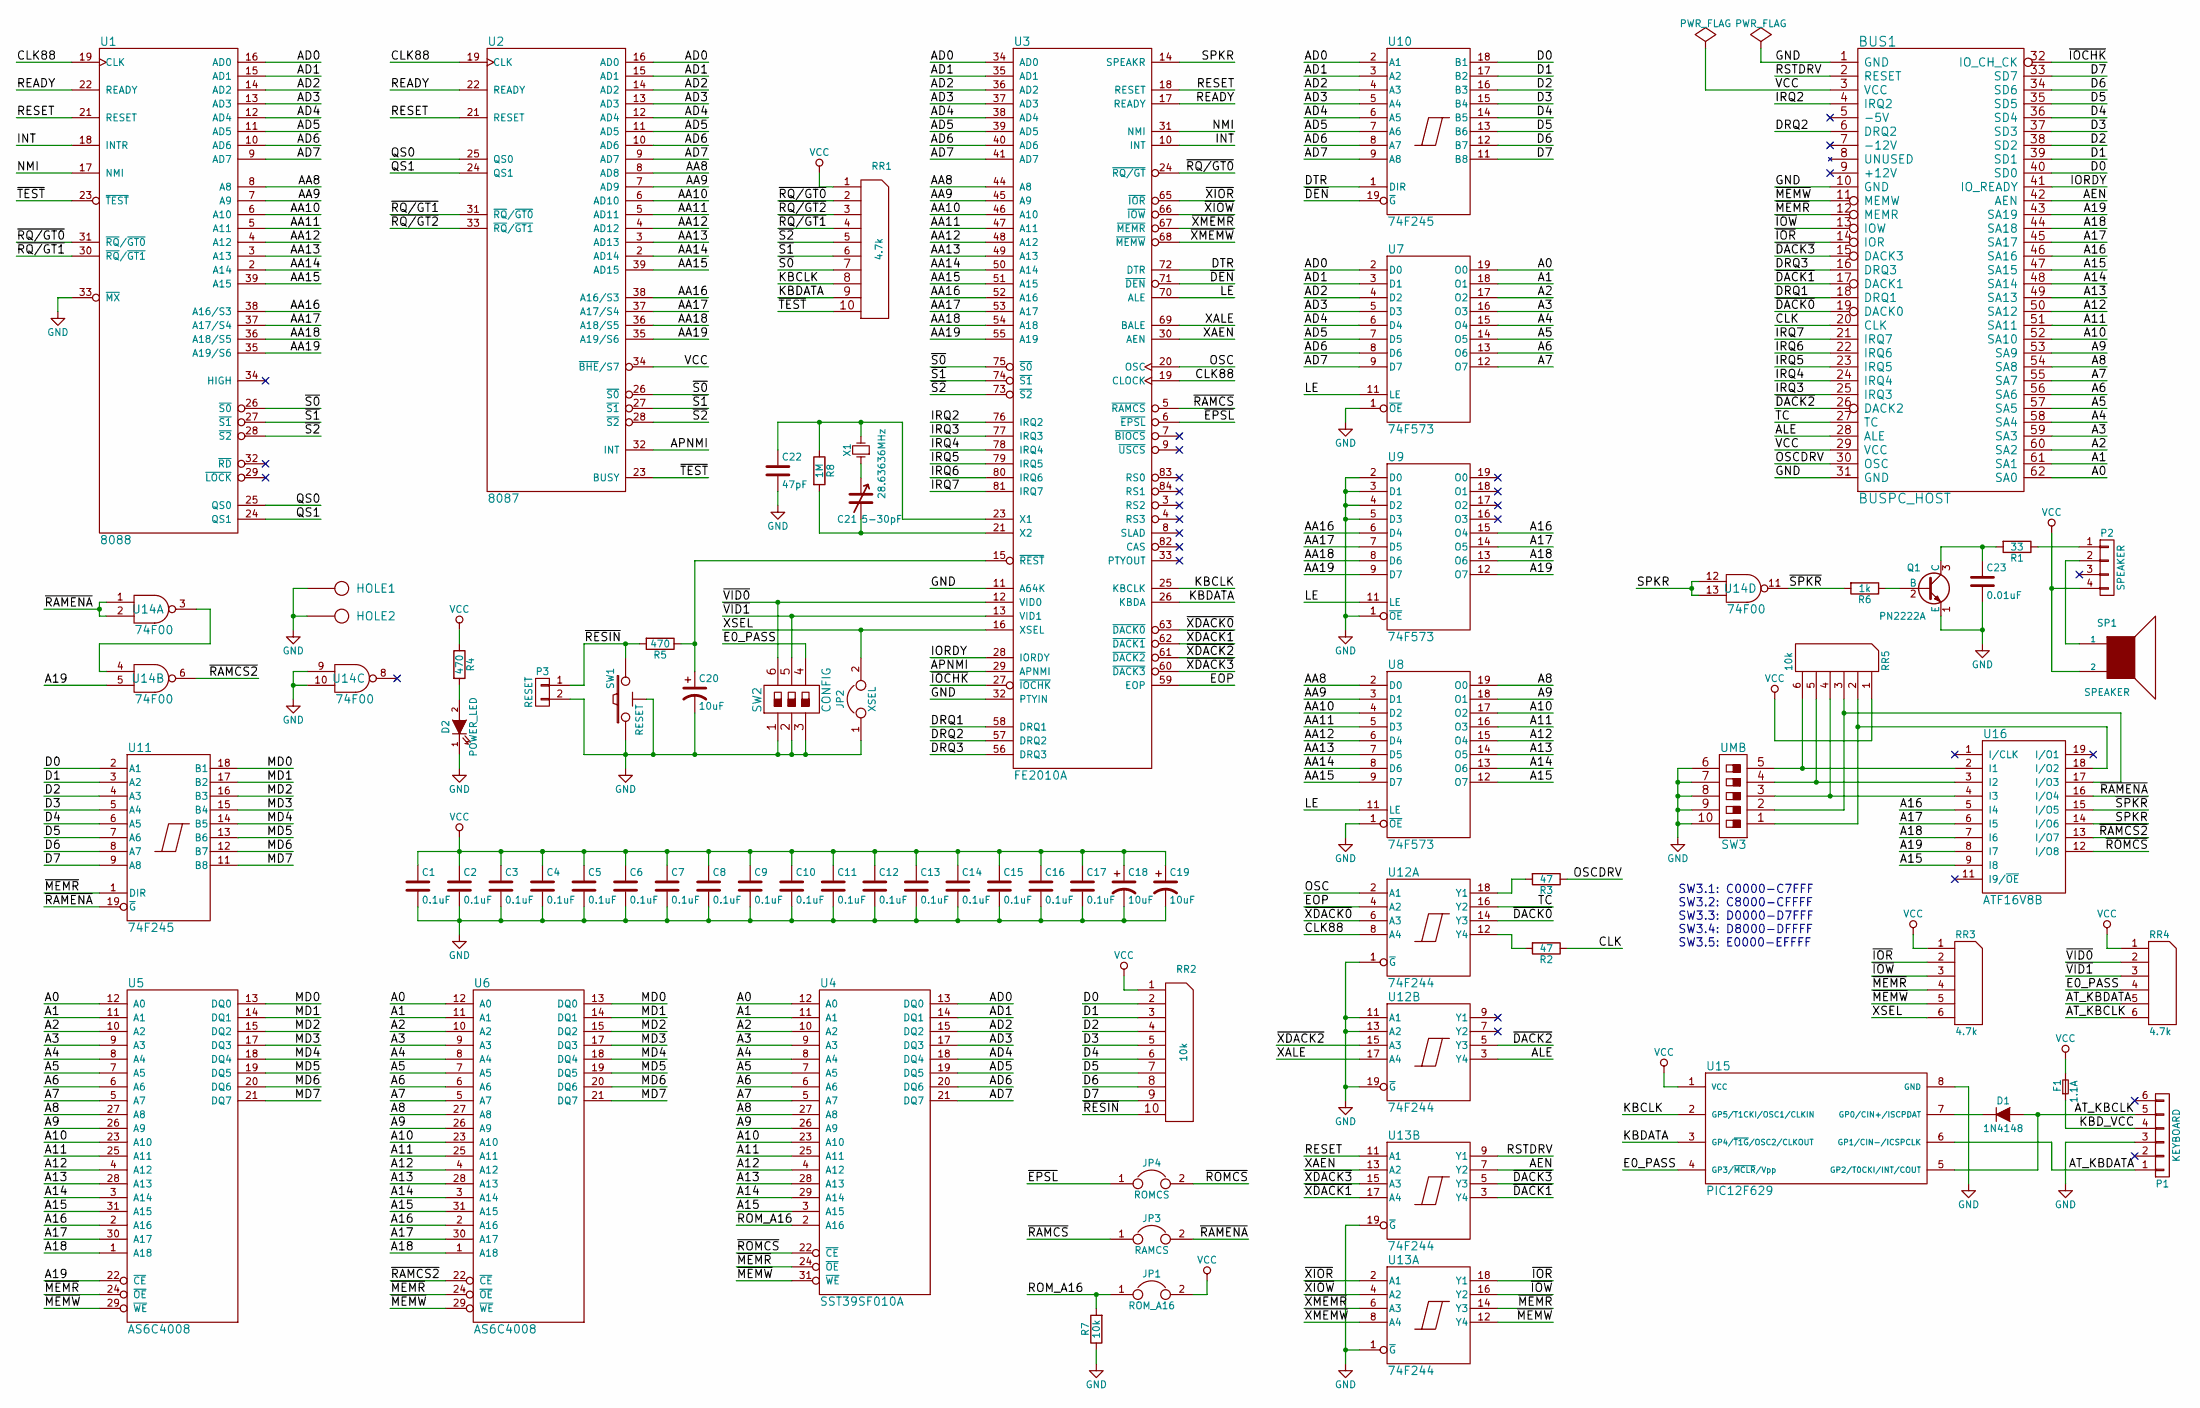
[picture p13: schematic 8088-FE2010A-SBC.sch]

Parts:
BUS1: BUSPC_HOST; Conn_Edge_PCB_ISA8
C1, C2, C3, C4, C5, C6, C7, C8, C9, C10, C11, C12, C13, C14, C15, C16, C17: 0.1uF; Cap_Cer_508
C18, C19, C20: 10uF; Cap_Tant_508
C21: 5-30pF; C_Trim_Murata
C22: 47pF; Cap_Cer_508
C23: 0.01uF; Cap_Cer_508
D1: 1N4148; Diode_762
D2: POWER_LED; LED_3mm
F1: 1.1A; Cap_Cer_508
HOLE1, HOLE2: HOLE; Hole_3mm
JP1: ROM_A16; Conn_Pin_Header_2x1_2.54mm_NoKey
JP2: XSEL; Conn_Pin_Header_2x1_2.54mm_NoKey
JP3: RAMCS; Conn_Pin_Header_2x1_2.54mm_NoKey
JP4: ROMCS; Conn_Pin_Header_2x1_2.54mm_NoKey
P1: KEYBOARD; Conn_Mini_DIN_6pin
P2: SPEAKER; Conn_Pin_Header_4x1_2.54mm
P3: RESET; Conn_Pin_Header_2x1_2.54mm
Q1: PN2222A; Transistor_TO92_EBC_254
R1: 33; Res_762
R2, R3: 47; Res_762
R4, R5: 470; Res_762
R6: 1k; Res_762
R7: 10k; Res_762
R8: 1M; Res_762
RR1: 4.7k; Conn_SIL10
RR2: 10k; Conn_SIL10
RR3, RR4: 4.7k; Conn_SIL6
RR5: 10k; Conn_SIL6
SP1: SPEAKER; Speaker_12mm
SW1: RESET; Switch_Tactile_6mm_Right
SW2: CONFIG; Switch_DIP_3_Positions
SW3: UMB; Switch_DIP_5_Positions
U1: 8088; IC_DIP40_600
U2: 8087; IC_DIP40_600
U3: FE2010A; IC_PLCC84_TH
U4: SST39SF010A; IC_DIP32_600
U5, U6: AS6C4008; IC_DIP32_600
U7, U8, U9: 74F573; IC_DIP20_300
U10, U11: 74F245; IC_DIP20_300
U12, U13: 74F244; IC_DIP20_300
U14: 74F00; IC_DIP14_300
U15: PIC12F629; IC_DIP8_300
U16: ATF16V8B; IC_DIP20_300
X1: 28.63636MHz; Crystal_HC-49U_Vert

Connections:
/A0: BUS1.62 (SA0), U4.12 (A0), U5.12 (A0), U6.12 (A0), U7.19 (O0)
/A1: BUS1.61 (SA1), U4.11 (A1), U5.11 (A1), U6.11 (A1), U7.18 (O1)
/A2: BUS1.60 (SA2), U4.10 (A2), U5.10 (A2), U6.10 (A2), U7.17 (O2)
/A3: BUS1.59 (SA3), U4.9 (A3), U5.9 (A3), U6.9 (A3), U7.16 (O3)
/A4: BUS1.58 (SA4), U4.8 (A4), U5.8 (A4), U6.8 (A4), U7.15 (O4)
/A5: BUS1.57 (SA5), U4.7 (A5), U5.7 (A5), U6.7 (A5), U7.14 (O5)
/A6: BUS1.56 (SA6), U4.6 (A6), U5.6 (A6), U6.6 (A6), U7.13 (O6)
/A7: BUS1.55 (SA7), U4.5 (A7), U5.5 (A7), U6.5 (A7), U7.12 (O7)
/A8: BUS1.54 (SA8), U4.27 (A8), U5.27 (A8), U6.27 (A8), U8.19 (O0)
/A9: BUS1.53 (SA9), U4.26 (A9), U5.26 (A9), U6.26 (A9), U8.18 (O1)
/A10: BUS1.52 (SA10), U4.23 (A10), U5.23 (A10), U6.23 (A10), U8.17 (O2)
/A11: BUS1.51 (SA11), U4.25 (A11), U5.25 (A11), U6.25 (A11), U8.16 (O3)
/A12: BUS1.50 (SA12), U4.4 (A12), U5.4 (A12), U6.4 (A12), U8.15 (O4)
/A13: BUS1.49 (SA13), U4.28 (A13), U5.28 (A13), U6.28 (A13), U8.14 (O5)
/A14: BUS1.48 (SA14), U4.29 (A14), U5.3 (A14), U6.3 (A14), U8.13 (O6)
/A15: BUS1.47 (SA15), U4.3 (A15), U5.31 (A15), U6.31 (A15), U8.12 (O7), U16.9 (I8)
/A16: BUS1.46 (SA16), U5.2 (A16), U6.2 (A16), U9.15 (O4), U16.5 (I4)
/A17: BUS1.45 (SA17), U5.30 (A17), U6.30 (A17), U9.14 (O5), U16.6 (I5)
/A18: BUS1.44 (SA18), U5.1 (A18), U6.1 (A18), U9.13 (O6), U16.7 (I6)
/A19: BUS1.43 (SA19), U5.22 (~CE), U9.12 (O7), U14.5, U16.8 (I7)
/AA8: U1.8 (A8), U2.8 (AD8), U3.44 (A8), U8.2 (D0)
/AA9: U1.7 (A9), U2.7 (AD9), U3.45 (A9), U8.3 (D1)
/AA10: U1.6 (A10), U2.6 (AD10), U3.46 (A10), U8.4 (D2)
/AA11: U1.5 (A11), U2.5 (AD11), U3.47 (A11), U8.5 (D3)
/AA12: U1.4 (A12), U2.4 (AD12), U3.48 (A12), U8.6 (D4)
/AA13: U1.3 (A13), U2.3 (AD13), U3.49 (A13), U8.7 (D5)
/AA14: U1.2 (A14), U2.2 (AD14), U3.50 (A14), U8.8 (D6)
/AA15: U1.39 (A15), U2.39 (AD15), U3.51 (A15), U8.9 (D7)
/AA16: U1.38 (A16/S3), U2.38 (A16/S3), U3.52 (A16), U9.6 (D4)
/AA17: U1.37 (A17/S4), U2.37 (A17/S4), U3.53 (A17), U9.7 (D5)
/AA18: U1.36 (A18/S5), U2.36 (A18/S5), U3.54 (A18), U9.8 (D6)
/AA19: U1.35 (A19/S6), U2.35 (A19/S6), U3.55 (A19), U9.9 (D7)
/AD0: U1.16 (AD0), U2.16 (AD0), U3.34 (AD0), U4.13 (DQ0), U7.2 (D0), U10.2 (A1)
/AD1: U1.15 (AD1), U2.15 (AD1), U3.35 (AD1), U4.14 (DQ1), U7.3 (D1), U10.3 (A2)
/AD2: U1.14 (AD2), U2.14 (AD2), U3.36 (AD2), U4.15 (DQ2), U7.4 (D2), U10.4 (A3)
/AD3: U1.13 (AD3), U2.13 (AD3), U3.37 (AD3), U4.17 (DQ3), U7.5 (D3), U10.5 (A4)
/AD4: U1.12 (AD4), U2.12 (AD4), U3.38 (AD4), U4.18 (DQ4), U7.6 (D4), U10.6 (A5)
/AD5: U1.11 (AD5), U2.11 (AD5), U3.39 (AD5), U4.19 (DQ5), U7.7 (D5), U10.7 (A6)
/AD6: U1.10 (AD6), U2.10 (AD6), U3.40 (AD6), U4.20 (DQ6), U7.8 (D6), U10.8 (A7)
/AD7: U1.9 (AD7), U2.9 (AD7), U3.41 (AD7), U4.21 (DQ7), U7.9 (D7), U10.9 (A8)
/AEN: BUS1.42 (AEN), U13.7 (Y2)
/ALE: BUS1.28 (ALE), U12.3 (Y4)
/APNMI: U2.32 (INT), U3.29 (APNMI)
/AT_KBCLK: D1.2 (A), P1.5, RR4.6, U15.5 (GP2/T0CKI/INT/COUT)
/AT_KBDATA: P1.1, RR4.5, U15.6 (GP1/CIN-/ICSPCLK)
/CLK: BUS1.20 (CLK), R2.1
/CLK88: U1.19 (CLK), U2.19 (CLK), U3.19 (CLOCK), U12.8 (A4)
/D0: BUS1.40 (SD0), RR2.2, U10.18 (B1), U11.2 (A1)
/D1: BUS1.39 (SD1), RR2.3, U10.17 (B2), U11.3 (A2)
/D2: BUS1.38 (SD2), RR2.4, U10.16 (B3), U11.4 (A3)
/D3: BUS1.37 (SD3), RR2.5, U10.15 (B4), U11.5 (A4)
/D4: BUS1.36 (SD4), RR2.6, U10.14 (B5), U11.6 (A5)
/D5: BUS1.35 (SD5), RR2.7, U10.13 (B6), U11.7 (A6)
/D6: BUS1.34 (SD6), RR2.8, U10.12 (B7), U11.8 (A7)
/D7: BUS1.33 (SD7), RR2.9, U10.11 (B8), U11.9 (A8)
/DRQ1: BUS1.18 (DRQ1), U3.58 (DRQ1)
/DRQ2: BUS1.6 (DRQ2), U3.57 (DRQ2)
/DRQ3: BUS1.16 (DRQ3), U3.56 (DRQ3)
/DTR: U3.72 (DTR), U10.1 (DIR)
/E0_PASS: RR4.4, SW2.4, U15.4 (GP3/~MCLR~/Vpp)
/EOP: U3.59 (EOP), U12.4 (A2)
/INT: U1.18 (INTR), U3.10 (INT)
/IORDY: BUS1.41 (IO_READY), U3.28 (IORDY)
/IRQ2: BUS1.4 (IRQ2), U3.76 (IRQ2)
/IRQ3: BUS1.25 (IRQ3), U3.77 (IRQ3)
/IRQ4: BUS1.24 (IRQ4), U3.78 (IRQ4)
/IRQ5: BUS1.23 (IRQ5), U3.79 (IRQ5)
/IRQ6: BUS1.22 (IRQ6), U3.80 (IRQ6)
/IRQ7: BUS1.21 (IRQ7), U3.81 (IRQ7)
/KBCLK: RR1.8, U3.25 (KBCLK), U15.2 (GP5/T1CKI/OSC1/CLKIN)
/KBDATA: RR1.9, U3.26 (KBDA), U15.3 (GP4/~T1G~/OSC2/CLKOUT)
/KBD_VCC: F1.1, P1.4
/LE: U3.70 (ALE), U7.11 (LE), U8.11 (LE), U9.11 (LE)
/MD0: U5.13 (DQ0), U6.13 (DQ0), U11.18 (B1)
/MD1: U5.14 (DQ1), U6.14 (DQ1), U11.17 (B2)
/MD2: U5.15 (DQ2), U6.15 (DQ2), U11.16 (B3)
/MD3: U5.17 (DQ3), U6.17 (DQ3), U11.15 (B4)
/MD4: U5.18 (DQ4), U6.18 (DQ4), U11.14 (B5)
/MD5: U5.19 (DQ5), U6.19 (DQ5), U11.13 (B6)
/MD6: U5.20 (DQ6), U6.20 (DQ6), U11.12 (B7)
/MD7: U5.21 (DQ7), U6.21 (DQ7), U11.11 (B8)
/NMI: U1.17 (NMI), U3.31 (NMI)
/OSC: U3.20 (OSC), U12.2 (A1)
/OSCDRV: BUS1.30 (OSC), R3.1
/QS0: U1.25 (QS0), U2.25 (QS0)
/QS1: U1.24 (QS1), U2.24 (QS1)
/READY: U1.22 (READY), U2.22 (READY), U3.17 (READY)
/RESET: U1.21 (RESET), U2.21 (RESET), U3.18 (RESET), U13.11 (A1)
/ROM_A16: JP1.1, R7.2, U4.2 (A16)
/RSTDRV: BUS1.2 (RESET), U13.9 (Y1)
/SPKR: U3.14 (SPEAKR), U14.12, U14.13, U16.14 (I/O6)
/TC: BUS1.27 (TC), U12.16 (Y2)
/XAEN: U3.30 (AEN), U13.13 (A2)
/XALE: U3.69 (BALE), U12.17 (A4)
/XSEL: JP2.2, RR3.6, U3.16 (XSEL)
/~DACK0: BUS1.19 (DACK0), U12.14 (Y3)
/~DACK1: BUS1.17 (DACK1), U13.3 (Y4)
/~DACK2: BUS1.26 (DACK2), U12.5 (Y3)
/~DACK3: BUS1.15 (DACK3), U13.5 (Y3)
/~DEN: U3.71 (~DEN), U10.19 (~G)
/~EPSL: JP4.1, U3.6 (~EPSL)
/~IOCHK: BUS1.32 (IO_CH_CK), U3.27 (~IOCHK)
/~IOR: BUS1.14 (IOR), RR3.2, U13.18 (Y1)
/~IOW: BUS1.13 (IOW), RR3.3, U13.16 (Y2)
/~MEMR: BUS1.12 (MEMR), RR3.4, U4.24 (~OE), U5.24 (~OE), U6.24 (~OE), U11.1 (DIR), U13.14 (Y3)
/~MEMW: BUS1.11 (MEMW), RR3.5, U4.31 (~WE), U5.29 (~WE), U6.29 (~WE), U13.12 (Y4)
/~RAMCS: JP3.1, U3.5 (~RAMCS)
/~RAMCS2: U6.22 (~CE), U14.6, U16.13 (I/O7)
/~RAMENA: JP3.2, U11.19 (~G), U14.1, U14.2, U16.16 (I/O4)
/~RESIN: P3.1, R5.2, RR2.10, SW1.2
/~ROMCS: JP4.2, U4.22 (~CE), U16.12 (I/O8)
/~RQ/GT0: RR1.2, U1.31 (~RQ~/~GT0~), U3.24 (~RQ/GT)
/~RQ/GT1: RR1.4, U1.30 (~RQ~/~GT1~), U2.31 (~RQ~/~GT0~)
/~RQ/GT2: RR1.3, U2.33 (~RQ~/~GT1~)
/~S0: RR1.7, U1.26 (~S0), U2.26 (~S0), U3.75 (~S0)
/~S1: RR1.6, U1.27 (~S1), U2.27 (~S1), U3.74 (~S1)
/~S2: RR1.5, U1.28 (~S2), U2.28 (~S2), U3.73 (~S2)
/~SPKR: R6.2, U14.11, U16.15 (I/O5)
/~TEST: RR1.10, U1.23 (~TEST), U2.23 (BUSY)
/~VID0: RR4.2, SW2.6, U3.12 (VID0)
/~VID1: RR4.3, SW2.5, U3.13 (VID1)
/~XDACK0: U3.63 (~DACK0), U12.6 (A3)
/~XDACK1: U3.62 (~DACK1), U13.17 (A4)
/~XDACK2: U3.61 (~DACK2), U12.15 (A3)
/~XDACK3: U3.60 (~DACK3), U13.15 (A3)
/~XIOR: U3.65 (~IOR), U13.2 (A1)
/~XIOW: U3.66 (~IOW), U13.4 (A2)
/~XMEMR: U3.67 (~MEMR), U13.6 (A3)
/~XMEMW: U3.68 (~MEMW), U13.8 (A4)
GND: BUS1.1 (GND), BUS1.10 (GND), BUS1.31 (GND), C1.2, C2.2, C3.2, C4.2, C5.2, C6.2, C7.2, C8.2, C9.2, C10.2, C11.2, C12.2, C13.2, C14.2, C15.2, C16.2, C17.2, C18.2, C19.2, C20.2, C22.2, C23.2, D2.1 (K), HOLE1.1, HOLE2.1, JP2.1, P1.3, P1.~, P3.2, Q1.1 (E), R7.1, SW1.1, SW1.GND, SW2.1, SW2.2, SW2.3, SW3.6, SW3.7, SW3.8, SW3.9, SW3.10, U1.1 (GND), U1.20 (GND), U1.33 (~MX), U2.1 (GND), U2.20 (GND), U3.2 (GND), U3.11 (A64K), U3.22 (GND), U3.32 (PTYIN), U3.42 (GND), U3.64 (GND), U4.16 (GND), U5.16 (GND), U6.16 (GND), U7.1 (~OE), U7.10 (GND), U8.1 (~OE), U8.10 (GND), U9.1 (~OE), U9.2 (D0), U9.3 (D1), U9.4 (D2), U9.5 (D3), U9.10 (GND), U10.10 (GND), U11.10 (GND), U12.1 (~G), U12.10 (GND), U12.11 (A1), U12.13 (A2), U12.19 (~G), U13.1 (~G), U13.10 (GND), U13.19 (~G), U14.7 (GND), U14.9, U14.10, U15.8 (GND), U16.10 (GND)
unnamed: C20.1, R5.1, U3.15 (~REST)
unnamed: C21.1, X1.1
unnamed: C21.2, R8.2, U3.21 (X2)
unnamed: C22.1, R8.1, U3.23 (X1), X1.2
unnamed: C23.1, Q1.3 (C), R1.2
unnamed: D1.1 (K), U15.7 (GP0/CIN+/ISCPDAT)
unnamed: D2.2 (A), R4.2
unnamed: P2.1, R1.1
unnamed: P2.2, SP1.1
unnamed: Q1.2 (B), R6.1
unnamed: R2.2, U12.12 (Y4)
unnamed: R3.2, U12.18 (Y1)
unnamed: RR5.2, SW3.1, U16.18 (I/O2)
unnamed: RR5.3, SW3.2, U16.17 (I/O3)
unnamed: RR5.4, SW3.3, U16.4 (I3)
unnamed: RR5.5, SW3.4, U16.3 (I2)
unnamed: RR5.6, SW3.5, U16.2 (I1)
unnamed: U14.3, U14.4
VCC: BUS1.3 (VCC), BUS1.29 (VCC), C1.1, C2.1, C3.1, C4.1, C5.1, C6.1, C7.1, C8.1, C9.1, C10.1, C11.1, C12.1, C13.1, C14.1, C15.1, C16.1, C17.1, C18.1, C19.1, F1.2, JP1.2, P2.4, R4.1, RR1.1 (COM), RR2.1 (COM), RR3.1 (COM), RR4.1 (COM), RR5.1 (COM), SP1.2, U1.40 (VCC), U2.34 (~BHE~/S7), U2.40 (VCC), U3.1 (VCC), U3.43 (VCC), U4.32 (VCC), U5.32 (VCC), U6.32 (VCC), U7.20 (VCC), U8.20 (VCC), U9.20 (VCC), U10.20 (VCC), U11.20 (VCC), U12.20 (VCC), U13.20 (VCC), U14.14 (VCC), U15.1 (VCC), U16.20 (VCC)

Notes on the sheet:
SW3.1: C0000-C7FFF SW3.2: C8000-CFFFF SW3.3: D0000-D7FFF SW3.4: D8000-DFFFF SW3.5: E0000-EFFFF

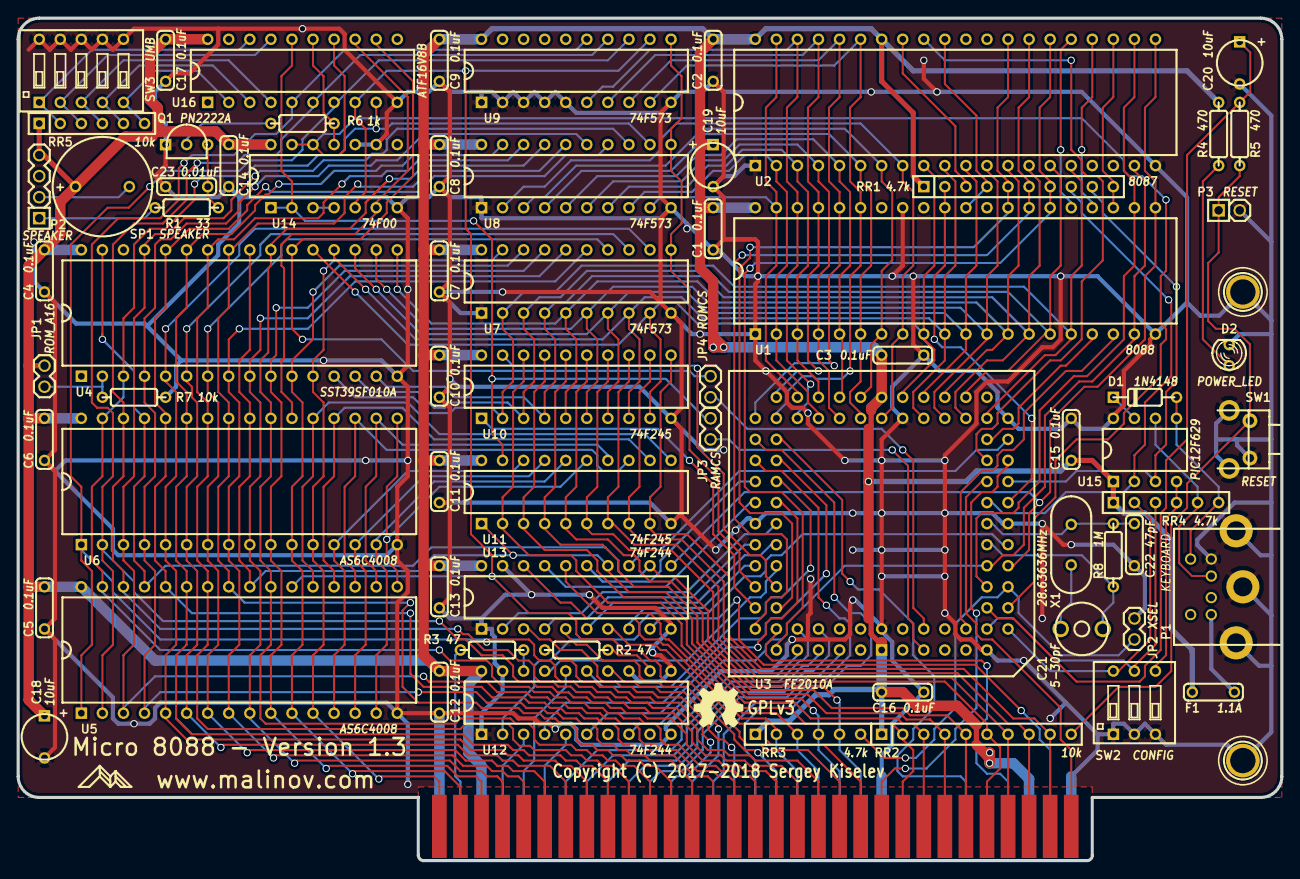
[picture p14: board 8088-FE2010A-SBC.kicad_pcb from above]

Board: 2 copper layers, 152.4 x 101.6 mm, 71 parts (0 on the bottom side), 149 nets.

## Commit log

2017-09-01 Initial drop - KiCad files for V1.0
    [8088-FE2010A-SBC.kicad_pcb, 8088-FE2010A-SBC.sch]
2017-09-01 Add bill of materials
2017-11-01 Add 1.1 files
    [8088-FE2010A-SBC-B.Mask.gbs, 8088-FE2010A-SBC-B.SilkS.gbo, 8088-FE2010A-SBC-Back.gbl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]
2017-11-02 Update for board version 1.1
2017-11-03 Update BOM for version 1.1
2017-11-23 SPLD: Renumber switch inputs according to schematic
2017-11-28 README: Add link to the Mouser BOM
2017-11-28 README: Add description for connectors, jumpers, and switches
2017-11-28 readme: Add OSH Park link, update PCB ordering information
2017-11-28 readme: Describe turbo mode switching
2018-09-20 Update for board version 1.2
    [8088-FE2010A-SBC.kicad_pcb]
2018-09-20 Update gerber files for board version 1.2
    [8088-FE2010A-SBC-B.Mask.gbs, 8088-FE2010A-SBC-B.SilkS.gbo, 8088-FE2010A-SBC-Back.gbl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]
2018-09-20 Update for board version 1.3
    [8088-FE2010A-SBC-B.Mask.gbs, 8088-FE2010A-SBC-B.SilkS.gbo, 8088-FE2010A-SBC-Back.gbl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]
2018-09-20 Update PCB version references in README to include versions 1.2 and 1.3
2020-04-01 README: Only one trimmer capacitor is needed
2020-04-02 Building Instructions: There are only 23 capacitors to solder
2021-11-19 README: Update BOM
    Update BOM:
    * Use resistor and resistor arrays that are available in single quantities from Mouser
    * Use Mini DIN PS/2 connector that is available from Mouser
    * Use TDK capacitors for uniformity and a bit of cost savings
    * Update notes on U14 and U16 being mutually exclusive
    * Add a note that the C21 trimmer capacitor can be replaced with a ceramic capacitor
    * Use cheaper FCI / Amphenol DIP sockets
2021-12-06 README: Mention Proton PT8010AF in the BoM

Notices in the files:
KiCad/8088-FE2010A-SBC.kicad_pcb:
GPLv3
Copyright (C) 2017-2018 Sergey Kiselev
